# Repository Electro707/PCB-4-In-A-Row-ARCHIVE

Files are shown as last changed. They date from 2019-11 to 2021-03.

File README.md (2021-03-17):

# PCB Digital 4-In-A-Row - ARCHIVED

This a PCB is a soldering kit for a 4-In-A-Row game. This specific repo is archived. Previously I didn't use a version manager, and thus I have difference folders for different revs, while now I want to start using git as a version manager (as well as proper releases and stuff). Thus there is a new clean repo for this project, and this is here for archival purposes. 

The new repo can be found here:
[https://github.com/Electro707/PCB-4-In-A-Row](https://github.com/Electro707/PCB-4-In-A-Row)

Rev A1:
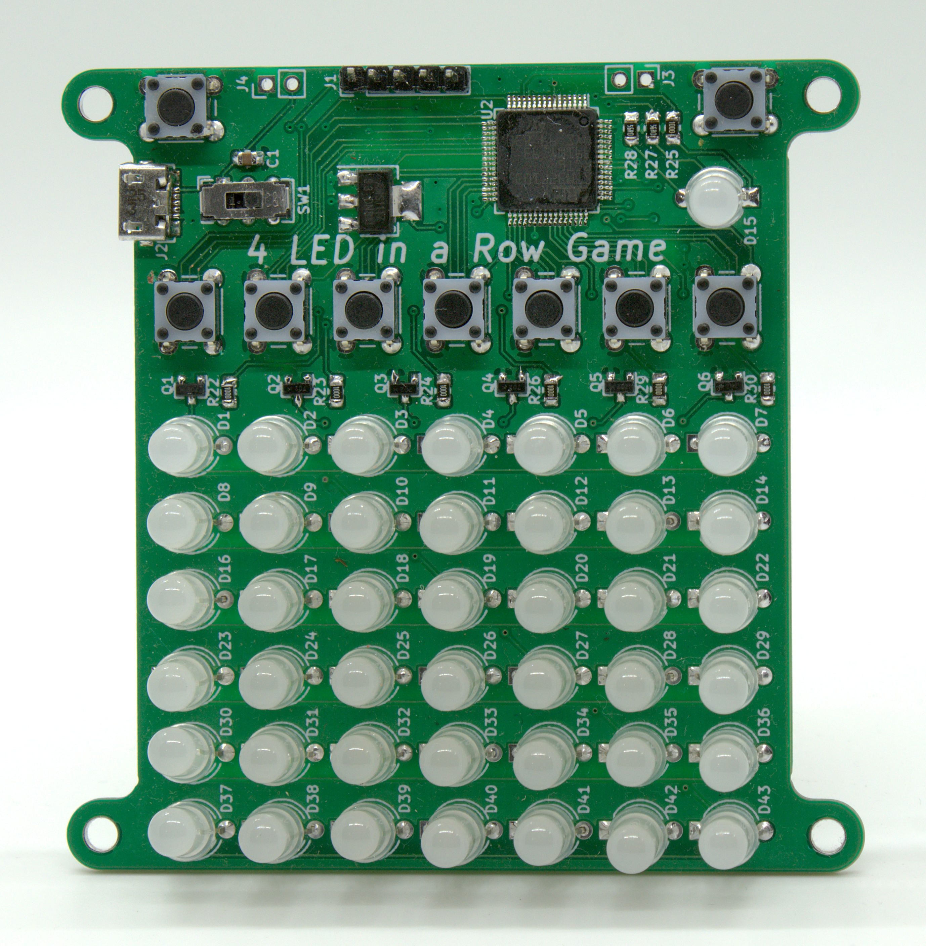
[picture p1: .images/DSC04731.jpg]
Rev A1

Rev A2:
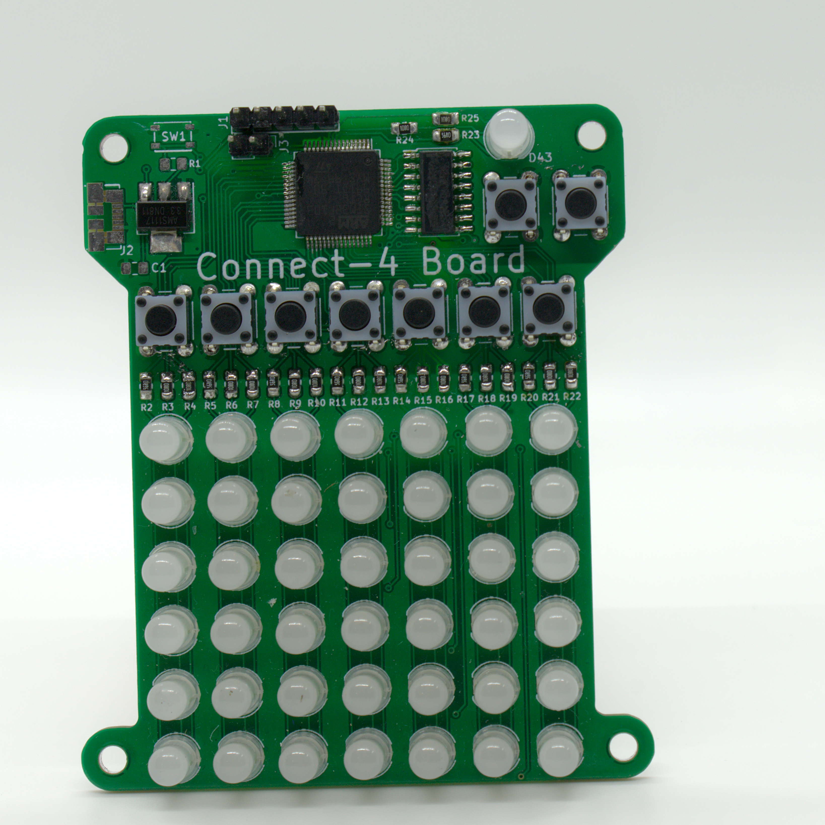
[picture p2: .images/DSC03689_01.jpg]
Rev A2

Latest Rev:
Latest Rev
## Authors

* **Jamal Bouajjaj** 

## License

See the [LICENSE.md](LICENSE.md) file for details

## Changelog 

What are those version? Well I have documented them under [CHANGELOG.md](CHANGELOG.md).

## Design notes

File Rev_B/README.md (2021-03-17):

## What is these patches??

Before I pushed the project files on GitHub, I had individual folders for each revision. So instead of having those folders uploaded, I decided to make them based on the Rev_B folder as different patches. To get the board, run the following command:

```
cd Rev_B
patch -p0 -t -R -E < ../revb*.patch
```

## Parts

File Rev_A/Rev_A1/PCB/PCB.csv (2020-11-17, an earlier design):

Source: | F:\Projects\Connect4 Board\PCB\PCB.sch
Date: | 11/10/2019 2:31:52 AM
Tool: | Eeschema (5.99.0-126-g64b5e8bee)
Component Count: | 89
Ref | Value | Footprint | Datasheet | Manufacturer | Vendor
C1 | C | Capacitor_SMD:C_0805_2012Metric_Pad1.15x1.40mm_HandSolder | ~
D1 | LED_RCGB | LED_THT:LED_D5.0mm-4_RGB | ~
D2 | LED_RCGB | LED_THT:LED_D5.0mm-4_RGB | ~
D3 | LED_RCGB | LED_THT:LED_D5.0mm-4_RGB | ~
D4 | LED_RCGB | LED_THT:LED_D5.0mm-4_RGB | ~
D5 | LED_RCGB | LED_THT:LED_D5.0mm-4_RGB | ~
D6 | LED_RCGB | LED_THT:LED_D5.0mm-4_RGB | ~
D7 | LED_RCGB | LED_THT:LED_D5.0mm-4_RGB | ~
D8 | LED_RCGB | LED_THT:LED_D5.0mm-4_RGB | ~
D9 | LED_RCGB | LED_THT:LED_D5.0mm-4_RGB | ~
D10 | LED_RCGB | LED_THT:LED_D5.0mm-4_RGB | ~
D11 | LED_RCGB | LED_THT:LED_D5.0mm-4_RGB | ~
D12 | LED_RCGB | LED_THT:LED_D5.0mm-4_RGB | ~
D13 | LED_RCGB | LED_THT:LED_D5.0mm-4_RGB | ~
D14 | LED_RCGB | LED_THT:LED_D5.0mm-4_RGB | ~
D15 | LED_RCGB | LED_THT:LED_D5.0mm-4_RGB | ~
D16 | LED_RCGB | LED_THT:LED_D5.0mm-4_RGB | ~
D17 | LED_RCGB | LED_THT:LED_D5.0mm-4_RGB | ~
D18 | LED_RCGB | LED_THT:LED_D5.0mm-4_RGB | ~
D19 | LED_RCGB | LED_THT:LED_D5.0mm-4_RGB | ~
D20 | LED_RCGB | LED_THT:LED_D5.0mm-4_RGB | ~
D21 | LED_RCGB | LED_THT:LED_D5.0mm-4_RGB | ~
D22 | LED_RCGB | LED_THT:LED_D5.0mm-4_RGB | ~
D23 | LED_RCGB | LED_THT:LED_D5.0mm-4_RGB | ~
D24 | LED_RCGB | LED_THT:LED_D5.0mm-4_RGB | ~
D25 | LED_RCGB | LED_THT:LED_D5.0mm-4_RGB | ~
D26 | LED_RCGB | LED_THT:LED_D5.0mm-4_RGB | ~
D27 | LED_RCGB | LED_THT:LED_D5.0mm-4_RGB | ~
D28 | LED_RCGB | LED_THT:LED_D5.0mm-4_RGB | ~
D29 | LED_RCGB | LED_THT:LED_D5.0mm-4_RGB | ~
D30 | LED_RCGB | LED_THT:LED_D5.0mm-4_RGB | ~
D31 | LED_RCGB | LED_THT:LED_D5.0mm-4_RGB | ~
D32 | LED_RCGB | LED_THT:LED_D5.0mm-4_RGB | ~
D33 | LED_RCGB | LED_THT:LED_D5.0mm-4_RGB | ~
D34 | LED_RCGB | LED_THT:LED_D5.0mm-4_RGB | ~
D35 | LED_RCGB | LED_THT:LED_D5.0mm-4_RGB | ~
D36 | LED_RCGB | LED_THT:LED_D5.0mm-4_RGB | ~
D37 | LED_RCGB | LED_THT:LED_D5.0mm-4_RGB | ~
D38 | LED_RCGB | LED_THT:LED_D5.0mm-4_RGB | ~
D39 | LED_RCGB | LED_THT:LED_D5.0mm-4_RGB | ~
D40 | LED_RCGB | LED_THT:LED_D5.0mm-4_RGB | ~
D41 | LED_RCGB | LED_THT:LED_D5.0mm-4_RGB | ~
D42 | LED_RCGB | LED_THT:LED_D5.0mm-4_RGB | ~
D43 | LED_RCGB | LED_THT:LED_D5.0mm-4_RGB | ~
H1 | 3.2mm Mounting Hole | MountingHole:MountingHole_3.2mm_M3 | ~
H2 | 3.2mm Mounting Hole | MountingHole:MountingHole_3.2mm_M3 | ~
H3 | 3.2mm Mounting Hole | MountingHole:MountingHole_3.2mm_M3 | ~
H4 | 3.2mm Mounting Hole | MountingHole:MountingHole_3.2mm_M3 | ~
J1 | Conn_01x05 | Connector_PinHeader_2.54mm:PinHeader_1x05_P2.54mm_Vertical | ~
J2 | USB_B_Micro | Connector_USB:USB_Micro-B_Molex_47346-0001 | ~
J3 | Power | Connector_PinHeader_2.54mm:PinHeader_1x02_P2.54mm_Vertical | ~
R1 | 1k | Resistor_SMD:R_0805_2012Metric_Pad1.15x1.40mm_HandSolder | ~
R2 | 560 | Resistor_SMD:R_0805_2012Metric_Pad1.15x1.40mm_HandSolder | ~
R3 | 560 | Resistor_SMD:R_0805_2012Metric_Pad1.15x1.40mm_HandSolder | ~
R4 | 560 | Resistor_SMD:R_0805_2012Metric_Pad1.15x1.40mm_HandSolder | ~
R5 | 560 | Resistor_SMD:R_0805_2012Metric_Pad1.15x1.40mm_HandSolder | ~
R6 | 560 | Resistor_SMD:R_0805_2012Metric_Pad1.15x1.40mm_HandSolder | ~
R7 | 560 | Resistor_SMD:R_0805_2012Metric_Pad1.15x1.40mm_HandSolder | ~
R8 | 560 | Resistor_SMD:R_0805_2012Metric_Pad1.15x1.40mm_HandSolder | ~
R9 | 560 | Resistor_SMD:R_0805_2012Metric_Pad1.15x1.40mm_HandSolder | ~
R10 | 560 | Resistor_SMD:R_0805_2012Metric_Pad1.15x1.40mm_HandSolder | ~
R11 | 560 | Resistor_SMD:R_0805_2012Metric_Pad1.15x1.40mm_HandSolder | ~
R12 | 560 | Resistor_SMD:R_0805_2012Metric_Pad1.15x1.40mm_HandSolder | ~
R13 | 560 | Resistor_SMD:R_0805_2012Metric_Pad1.15x1.40mm_HandSolder | ~
R14 | 560 | Resistor_SMD:R_0805_2012Metric_Pad1.15x1.40mm_HandSolder | ~
R15 | 560 | Resistor_SMD:R_0805_2012Metric_Pad1.15x1.40mm_HandSolder | ~
R16 | 560 | Resistor_SMD:R_0805_2012Metric_Pad1.15x1.40mm_HandSolder | ~
R17 | 560 | Resistor_SMD:R_0805_2012Metric_Pad1.15x1.40mm_HandSolder | ~
R18 | 560 | Resistor_SMD:R_0805_2012Metric_Pad1.15x1.40mm_HandSolder | ~
R19 | 560 | Resistor_SMD:R_0805_2012Metric_Pad1.15x1.40mm_HandSolder | ~
R20 | 560 | Resistor_SMD:R_0805_2012Metric_Pad1.15x1.40mm_HandSolder | ~
R21 | 560 | Resistor_SMD:R_0805_2012Metric_Pad1.15x1.40mm_HandSolder | ~
R22 | 560 | Resistor_SMD:R_0805_2012Metric_Pad1.15x1.40mm_HandSolder | ~
R23 | 560 | Resistor_SMD:R_0805_2012Metric_Pad1.15x1.40mm_HandSolder | ~
R24 | 560 | Resistor_SMD:R_0805_2012Metric_Pad1.15x1.40mm_HandSolder | ~
R25 | 560 | Resistor_SMD:R_0805_2012Metric_Pad1.15x1.40mm_HandSolder | ~
SW1 | SW_Push | Button_Switch_SMD:SW_SPST_PTS810 | ~
SW2 | SW_Push | Button_Switch_THT:SW_PUSH_6mm_H5mm
SW3 | SW_Push | Button_Switch_THT:SW_PUSH_6mm_H5mm
SW4 | SW_Push | Button_Switch_THT:SW_PUSH_6mm_H5mm
SW5 | SW_Push | Button_Switch_THT:SW_PUSH_6mm_H5mm
SW6 | SW_Push | Button_Switch_THT:SW_PUSH_6mm_H5mm
SW7 | SW_Push | Button_Switch_THT:SW_PUSH_6mm_H5mm
SW8 | SW_Push | Button_Switch_THT:SW_PUSH_6mm_H5mm
SW9 | SW_Push | Button_Switch_THT:SW_PUSH_6mm_H5mm
SW10 | SW_Push | Button_Switch_THT:SW_PUSH_6mm_H5mm
U1 | AMS1117-3.3 | Package_TO_SOT_SMD:SOT-223-3_TabPin2 | http://www.advanced-monolithic.com/pdf/ds1117.pdf
U2 | ULN2003 | Package_SO:SOP-16_4.55x10.3mm_P1.27mm | http://www.ti.com/lit/ds/symlink/uln2003a.pdf
U3 | STM32F103RCTx | Package_QFP:LQFP-64_10x10mm_P0.5mm | http://www.st.com/st-web-ui/static/active/en/resource/technical/document/datasheet/CD00191185.pdf

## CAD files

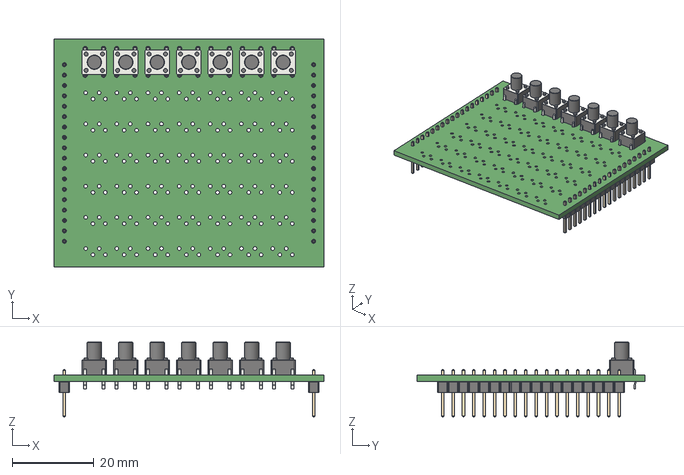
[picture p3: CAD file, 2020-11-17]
Rev_B/Rev_B/LED PCB/LED_PCB.step
66.0 x 55.9 x 18.2 mm

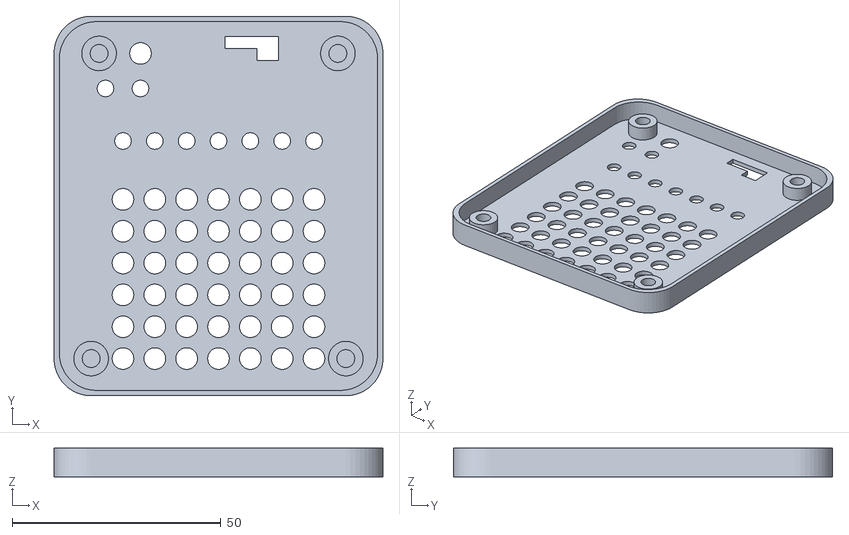
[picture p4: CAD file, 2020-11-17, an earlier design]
Rev_A/Rev_A1/CAD (Fusion360 Exports)/Case Top v24.stl
78.7 x 90.8 x 6.87

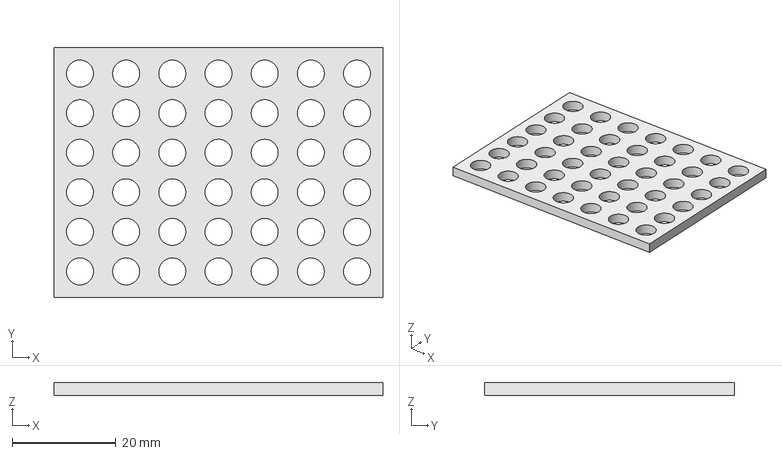
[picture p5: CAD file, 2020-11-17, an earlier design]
Rev_A/Rev_A2/LED Holder.FCStd
63.3 x 48.1 x 2.50 mm

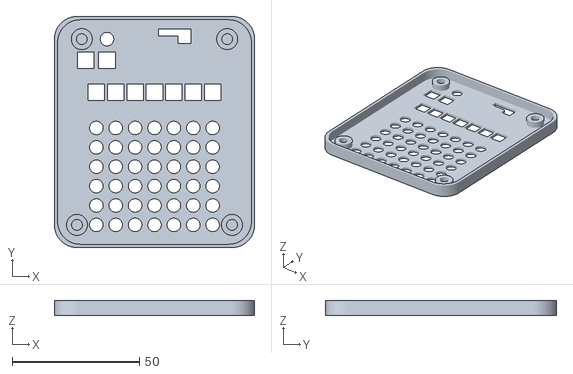
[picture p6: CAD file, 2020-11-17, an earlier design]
Rev_A/Rev_A1/CAD (Fusion360 Exports)/Case Top v29.stl
78.7 x 90.8 x 5.97

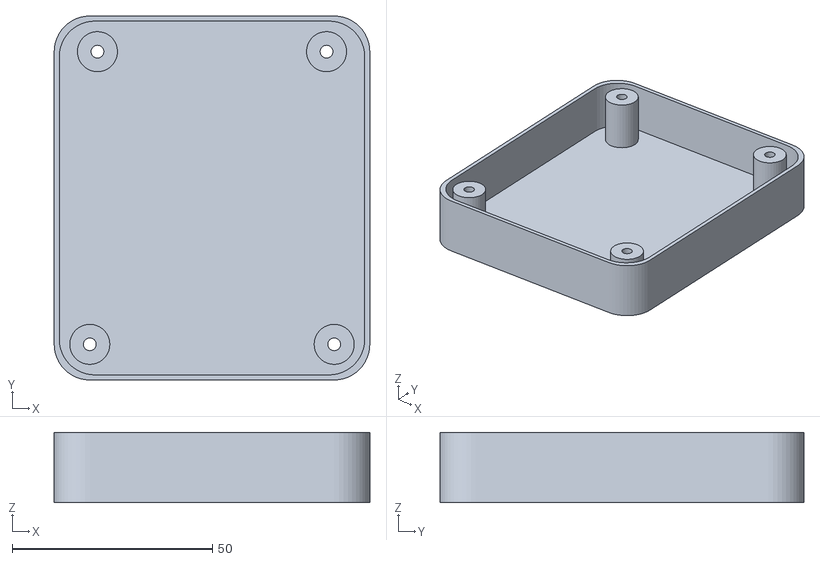
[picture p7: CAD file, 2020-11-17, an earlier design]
Rev_A/Rev_A1/CAD (Fusion360 Exports)/Buttom.stl
78.7 x 90.8 x 17.5

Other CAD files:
Rev_A/Rev_A1/CAD (Fusion360 Exports)/OldVersions/Drawing.0003.dwg
Rev_A/Rev_A1/CAD (Fusion360 Exports)/Case Top v27.stl
Rev_A/Rev_A1/CAD (Fusion360 Exports)/Drawing.dwg
Rev_A/Rev_A1/CAD (Fusion360 Exports)/Buttom Part.ipt
Rev_A/Rev_A1/CAD (Fusion360 Exports)/OldVersions/Buttom Part.0009.ipt
Rev_A/Rev_A1/CAD (Fusion360 Exports)/OldVersions/Top Part.0003.ipt
Rev_A/Rev_A1/CAD (Fusion360 Exports)/OldVersions/Whole-Assembly.0002.iam
Rev_A/Rev_A1/CAD (Fusion360 Exports)/OldVersions/Whole-Assembly.0003.iam
Rev_A/Rev_A1/CAD (Fusion360 Exports)/Top Part.ipt
Rev_A/Rev_A1/CAD (Fusion360 Exports)/Whole-Assembly.iam

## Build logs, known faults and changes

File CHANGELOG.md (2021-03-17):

This document describes the changes between the different revision:

- Rev A:
    - Rev A1:
        - Initial Release/Design
    - Rev A2: 
        - Updated to a more symetrical design. 
        - Added on-off switch
        - Replaced Darlington transistor pair IC with individual MOSFETs
- Rev B:
    - Rev B1:
        - Complete redesign to use an ATmega328P and 74HC595s instead of the STM32
        - Seperated the driver board and LED board
    - Rev B2:
        - Changed Micro-USB to USB-B
        - Added transistors to drive the rows (to allow more than 1 LED on at a time)
    - Rev B3:
        - Removed "Connect-4" trademarked silkscreen text (except I forgot to change it in the back of the PCB)
    - Rev B4:
        - Added FT230X for easy programming
        - Changed ALL "Connect-4" references to "4-In-A-Row" due to potential trademark issues
    - Rev B5 (Last one before repo archiving. Moved over to new project repo):
        - Fixed reversed USB+ and USB- data connections to the FT230X
        - Changed some silkscreen text

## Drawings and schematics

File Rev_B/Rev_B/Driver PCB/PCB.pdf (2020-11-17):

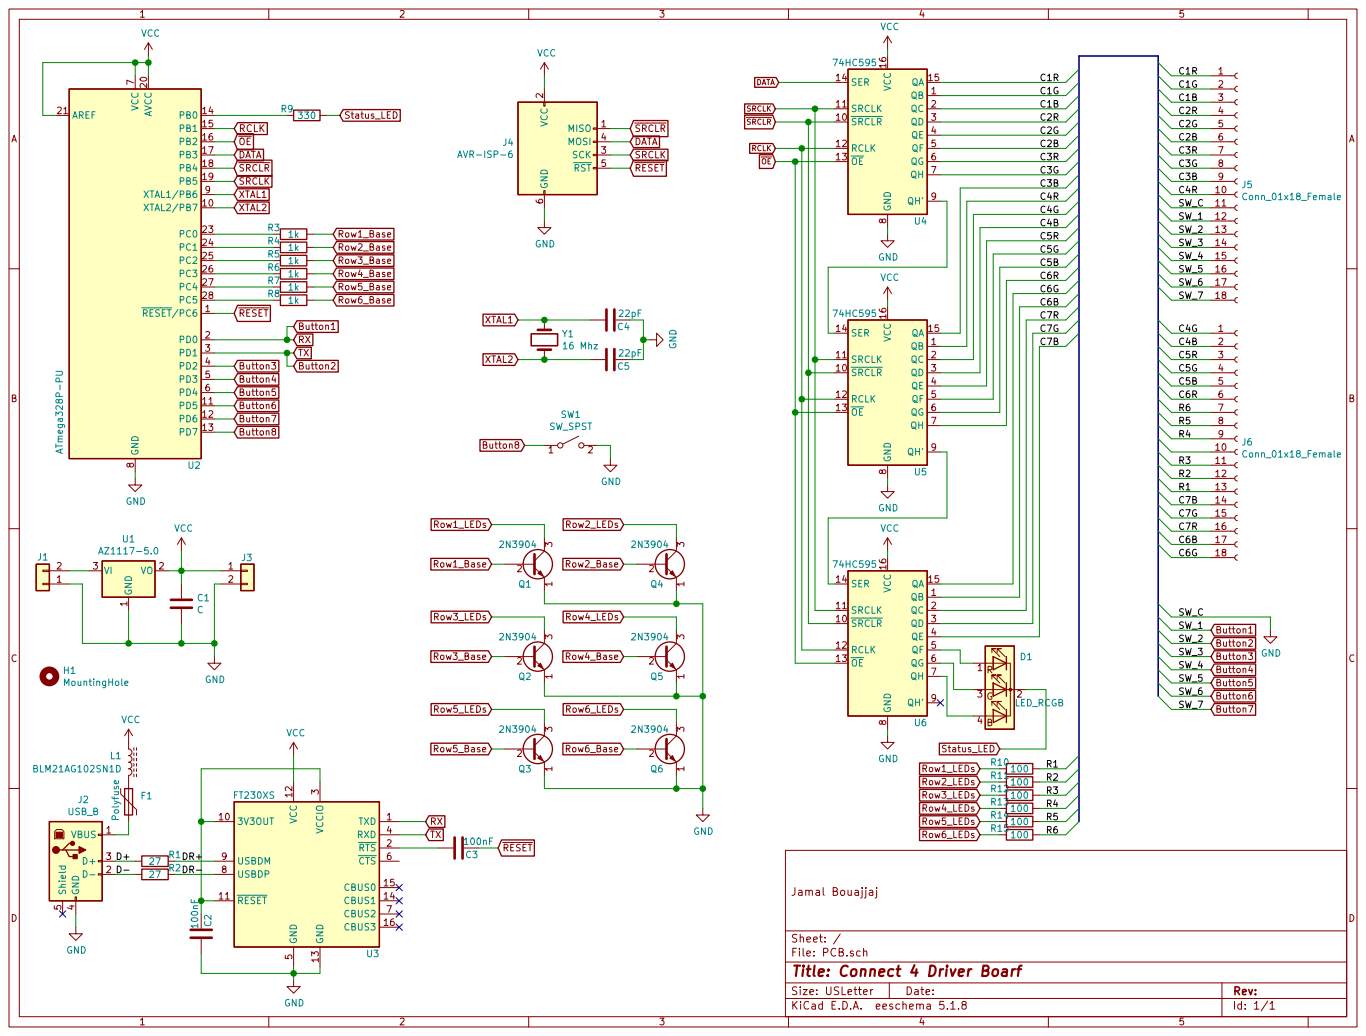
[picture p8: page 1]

Id: 1/1 Title: Connect 4 Driver Boarf File: PCB.sch Sheet: / Jamal Bouajjaj

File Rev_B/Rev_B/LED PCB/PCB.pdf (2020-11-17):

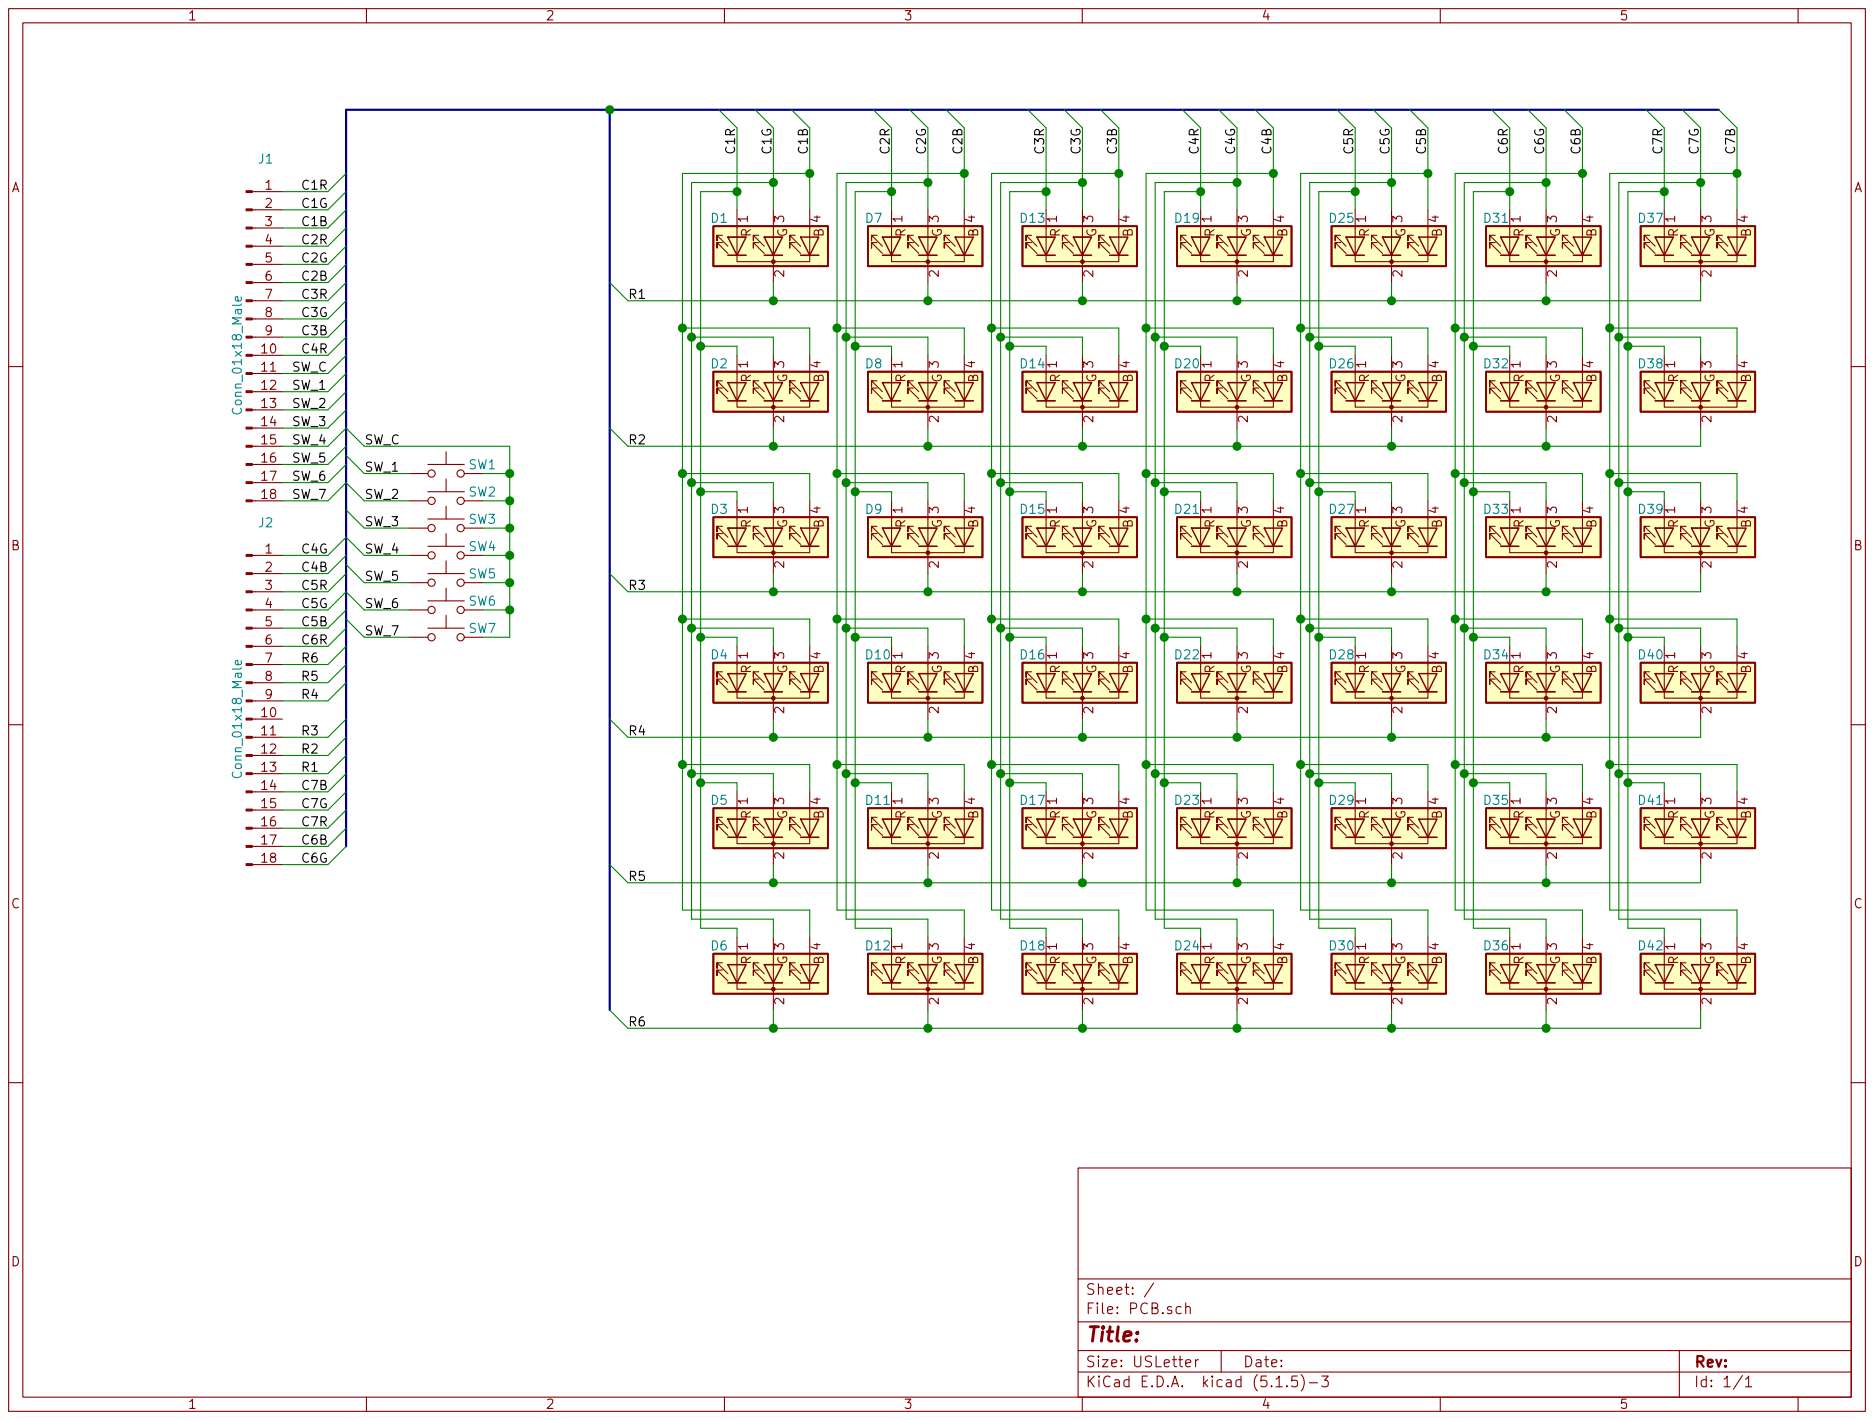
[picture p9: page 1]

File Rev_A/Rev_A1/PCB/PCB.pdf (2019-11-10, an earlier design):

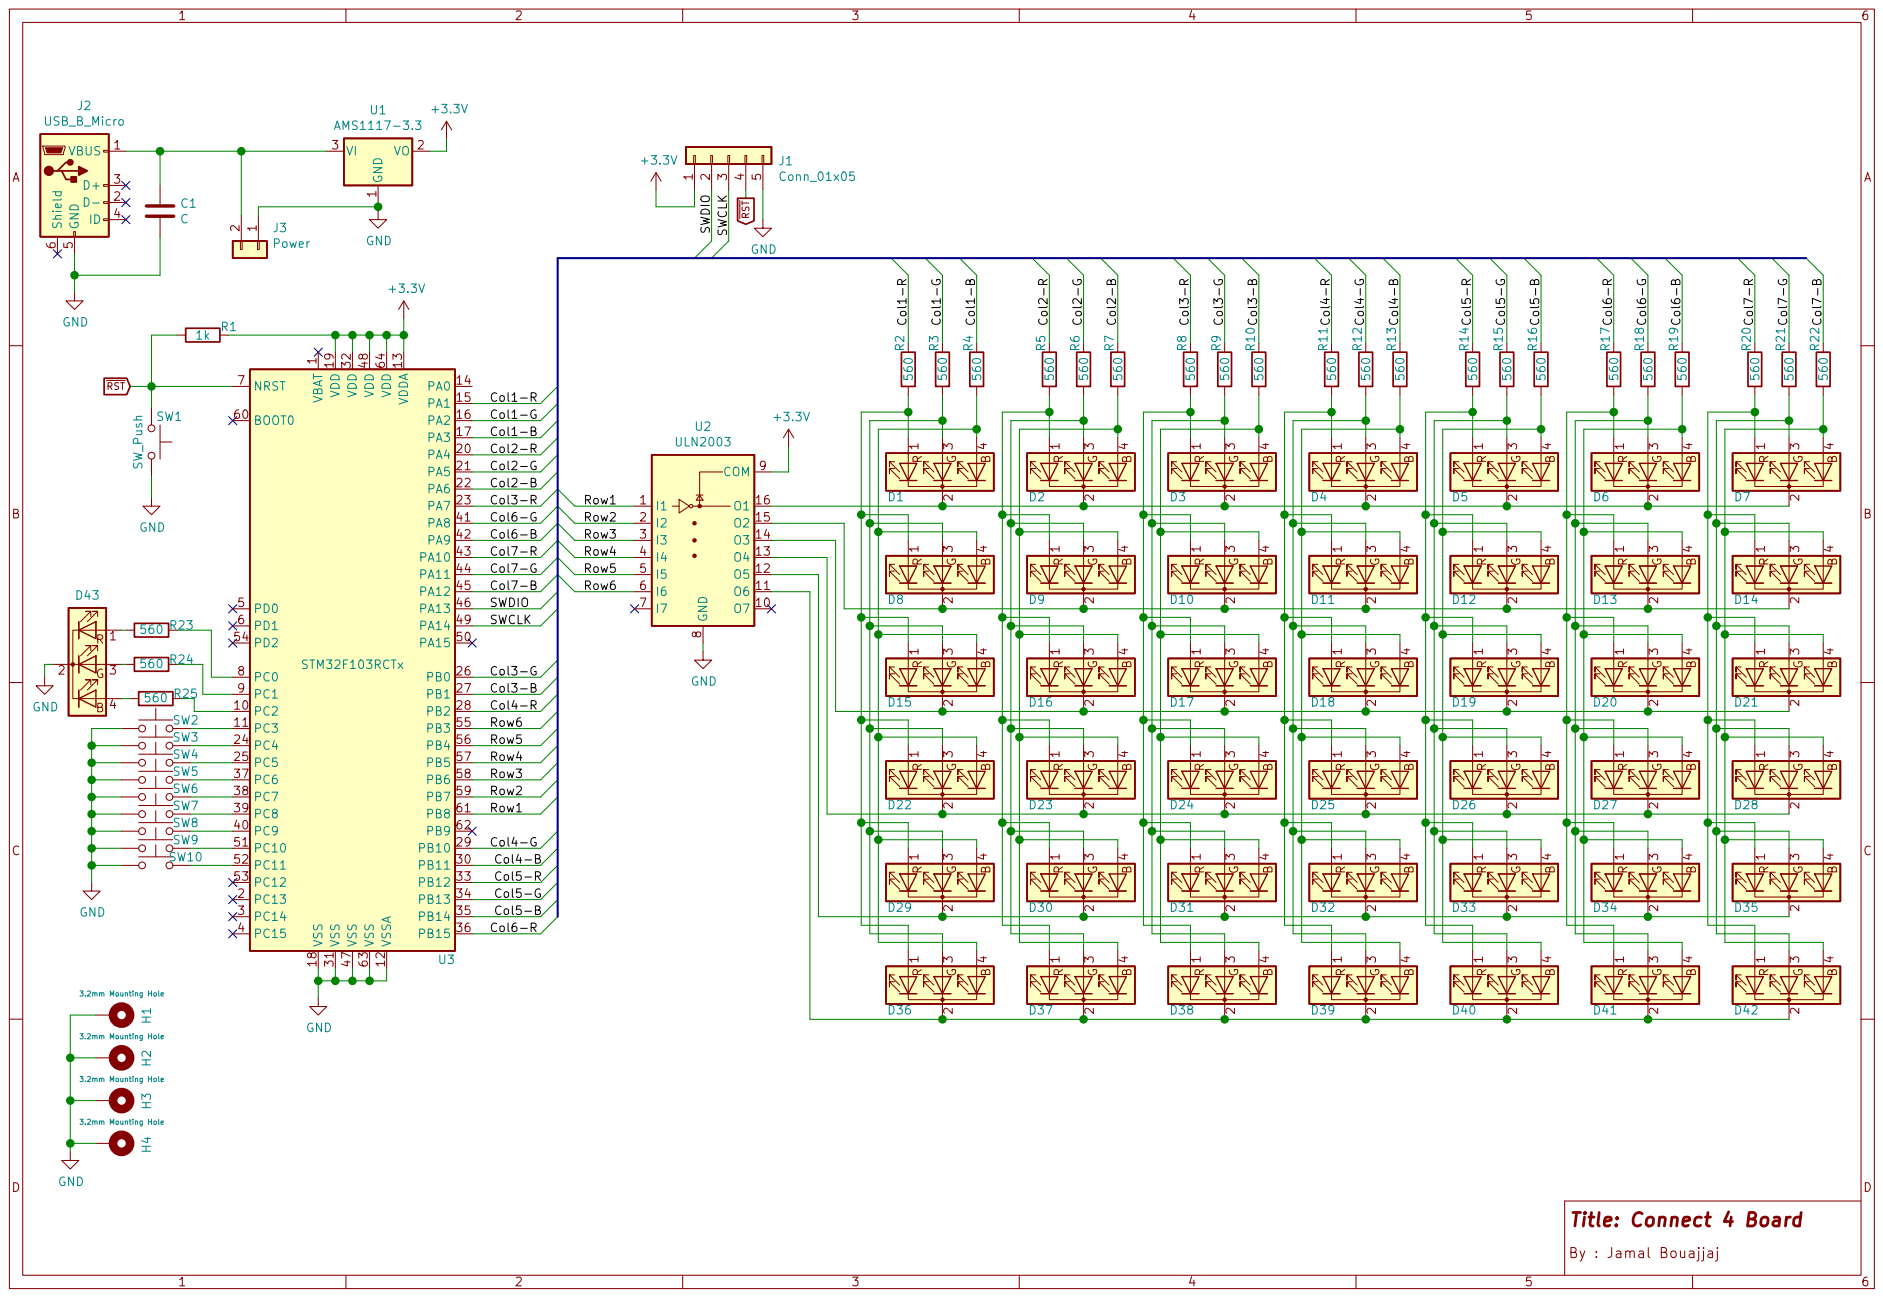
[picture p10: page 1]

1 VDD 19 VDD 32 VDD 48 VDD 64 VDDA 13 VSS 18 VSS 31 VSS 47 VSS 63 VSSA 12U3 STM32F103RCTx 2

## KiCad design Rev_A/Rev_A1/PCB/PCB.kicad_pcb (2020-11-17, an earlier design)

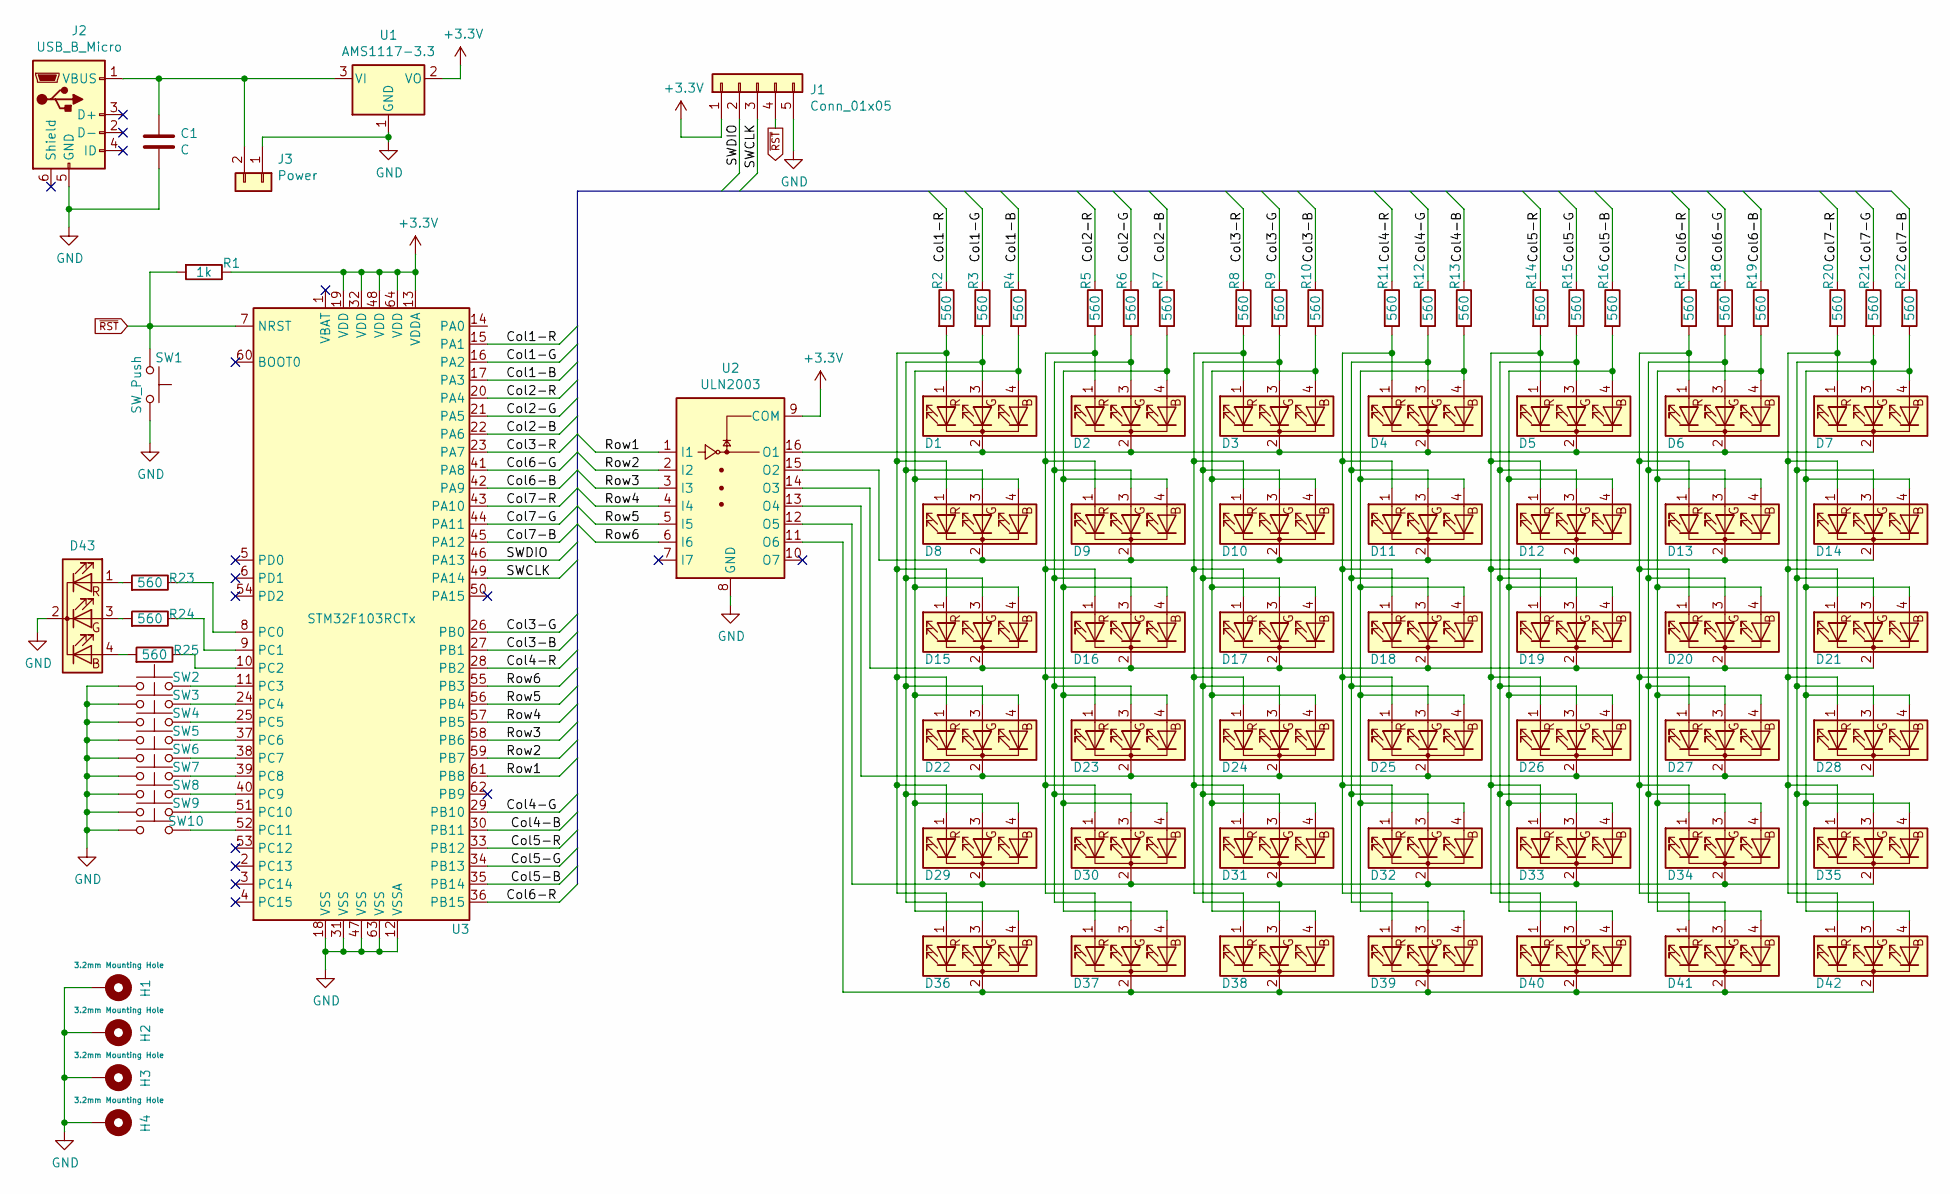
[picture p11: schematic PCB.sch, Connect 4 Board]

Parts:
C1: C; C_0805_2012Metric_Pad1.15x1.40mm_HandSolder
D1, D2, D3, D4, D5, D6, D7, D8, D9, D10, D11, D12, D13, D14, D15, D16, D17, D18, D19, D20, D21, D22, D23, D24, D25, D26, D27, D28, D29, D30, D31, D32, D33, D34, D35, D36, D37, D38, D39, D40, D41, D42, D43: LED_RCGB; LED_D5.0mm-4_RGB
H1, H2, H3, H4: 3.2mm Mounting Hole; MountingHole_3.2mm_M3
J1: Conn_01x05; PinHeader_1x05_P2.54mm_Vertical
J2: USB_B_Micro; USB_Micro-B_Molex_47346-0001
J3: Power; PinHeader_1x02_P2.54mm_Vertical
R1: 1k; R_0805_2012Metric_Pad1.15x1.40mm_HandSolder
R2, R3, R4, R5, R6, R7, R8, R9, R10, R11, R12, R13, R14, R15, R16, R17, R18, R19, R20, R21, R22, R23, R24, R25: 560; R_0805_2012Metric_Pad1.15x1.40mm_HandSolder
SW1: SW_Push; SW_SPST_PTS810
SW2, SW3, SW4, SW5, SW6, SW7, SW8, SW9, SW10: SW_Push; SW_PUSH_6mm_H5mm
U1: AMS1117-3.3; SOT-223-3_TabPin2
U2: ULN2003; SOP-16_4.55x10.3mm_P1.27mm
U3: STM32F103RCTx; LQFP-64_10x10mm_P0.5mm

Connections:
+3V3: J1.1, R1.1, U1.2 (VO), U2.9 (COM), U3.13 (VDDA), U3.19 (VDD), U3.32 (VDD), U3.48 (VDD), U3.64 (VDD)
/Col1-B: R4.1, U3.17 (PA3)
/Col1-G: R3.1, U3.16 (PA2)
/Col1-R: R2.1, U3.15 (PA1)
/Col2-B: R7.1, U3.22 (PA6)
/Col2-G: R6.1, U3.21 (PA5)
/Col2-R: R5.1, U3.20 (PA4)
/Col3-B: R10.1, U3.27 (PB1)
/Col3-G: R9.1, U3.26 (PB0)
/Col3-R: R8.1, U3.23 (PA7)
/Col4-B: R13.1, U3.30 (PB11)
/Col4-G: R12.1, U3.29 (PB10)
/Col4-R: R11.1, U3.28 (PB2)
/Col5-B: R16.1, U3.35 (PB14)
/Col5-G: R15.1, U3.34 (PB13)
/Col5-R: R14.1, U3.33 (PB12)
/Col6-B: R19.1, U3.42 (PA9)
/Col6-G: R18.1, U3.41 (PA8)
/Col6-R: R17.1, U3.36 (PB15)
/Col7-B: R22.1, U3.45 (PA12)
/Col7-G: R21.1, U3.44 (PA11)
/Col7-R: R20.1, U3.43 (PA10)
/Row1: U2.1 (I1), U3.61 (PB8)
/Row2: U2.2 (I2), U3.59 (PB7)
/Row3: U2.3 (I3), U3.58 (PB6)
/Row4: U2.4 (I4), U3.57 (PB5)
/Row5: U2.5 (I5), U3.56 (PB4)
/Row6: U2.6 (I6), U3.55 (PB3)
/SWCLK: J1.3, U3.49 (PA14)
/SWDIO: J1.2, U3.46 (PA13)
GND: C1.2, D43.2 (K), H1.1, H2.1, H3.1, H4.1, J1.5, J2.5 (GND), J3.1, SW1.2, SW2.1, SW3.1, SW4.1, SW5.1, SW6.1, SW7.1, SW8.1, SW9.1, SW10.1, U1.1 (GND), U2.8 (GND), U3.12 (VSSA), U3.18 (VSS), U3.31 (VSS), U3.47 (VSS), U3.63 (VSS)
unnamed: C1.1, J2.1 (VBUS), J3.2, U1.3 (VI)
unnamed: D1.1 (RA), D8.1 (RA), D15.1 (RA), D22.1 (RA), D29.1 (RA), D36.1 (RA), R2.2
unnamed: D1.2 (K), D2.2 (K), D3.2 (K), D4.2 (K), D5.2 (K), D6.2 (K), D7.2 (K), U2.16 (O1)
unnamed: D1.3 (GA), D8.3 (GA), D15.3 (GA), D22.3 (GA), D29.3 (GA), D36.3 (GA), R3.2
unnamed: D1.4 (BA), D8.4 (BA), D15.4 (BA), D22.4 (BA), D29.4 (BA), D36.4 (BA), R4.2
unnamed: D3.1 (RA), D10.1 (RA), D17.1 (RA), D24.1 (RA), D31.1 (RA), D38.1 (RA), R8.2
unnamed: D8.2 (K), D9.2 (K), D10.2 (K), D11.2 (K), D12.2 (K), D13.2 (K), D14.2 (K), U2.15 (O2)
unnamed: D3.3 (GA), D10.3 (GA), D17.3 (GA), D24.3 (GA), D31.3 (GA), D38.3 (GA), R9.2
unnamed: D3.4 (BA), D10.4 (BA), D17.4 (BA), D24.4 (BA), D31.4 (BA), D38.4 (BA), R10.2
unnamed: D4.1 (RA), D11.1 (RA), D18.1 (RA), D25.1 (RA), D32.1 (RA), D39.1 (RA), R11.2
unnamed: D4.3 (GA), D11.3 (GA), D18.3 (GA), D25.3 (GA), D32.3 (GA), D39.3 (GA), R12.2
unnamed: D4.4 (BA), D11.4 (BA), D18.4 (BA), D25.4 (BA), D32.4 (BA), D39.4 (BA), R13.2
unnamed: D5.1 (RA), D12.1 (RA), D19.1 (RA), D26.1 (RA), D33.1 (RA), D40.1 (RA), R14.2
unnamed: D5.3 (GA), D12.3 (GA), D19.3 (GA), D26.3 (GA), D33.3 (GA), D40.3 (GA), R15.2
unnamed: D5.4 (BA), D12.4 (BA), D19.4 (BA), D26.4 (BA), D33.4 (BA), D40.4 (BA), R16.2
unnamed: D6.1 (RA), D13.1 (RA), D20.1 (RA), D27.1 (RA), D34.1 (RA), D41.1 (RA), R17.2
unnamed: D6.3 (GA), D13.3 (GA), D20.3 (GA), D27.3 (GA), D34.3 (GA), D41.3 (GA), R18.2
unnamed: D6.4 (BA), D13.4 (BA), D20.4 (BA), D27.4 (BA), D34.4 (BA), D41.4 (BA), R19.2
unnamed: D7.1 (RA), D14.1 (RA), D21.1 (RA), D28.1 (RA), D35.1 (RA), D42.1 (RA), R20.2
unnamed: D7.3 (GA), D14.3 (GA), D21.3 (GA), D28.3 (GA), D35.3 (GA), D42.3 (GA), R21.2
unnamed: D7.4 (BA), D14.4 (BA), D21.4 (BA), D28.4 (BA), D35.4 (BA), D42.4 (BA), R22.2
unnamed: D15.2 (K), D16.2 (K), D17.2 (K), D18.2 (K), D19.2 (K), D20.2 (K), D21.2 (K), U2.14 (O3)
unnamed: D2.1 (RA), D9.1 (RA), D16.1 (RA), D23.1 (RA), D30.1 (RA), D37.1 (RA), R5.2
unnamed: D2.3 (GA), D9.3 (GA), D16.3 (GA), D23.3 (GA), D30.3 (GA), D37.3 (GA), R6.2
unnamed: D2.4 (BA), D9.4 (BA), D16.4 (BA), D23.4 (BA), D30.4 (BA), D37.4 (BA), R7.2
unnamed: D22.2 (K), D23.2 (K), D24.2 (K), D25.2 (K), D26.2 (K), D27.2 (K), D28.2 (K), U2.13 (O4)
unnamed: D29.2 (K), D30.2 (K), D31.2 (K), D32.2 (K), D33.2 (K), D34.2 (K), D35.2 (K), U2.12 (O5)
unnamed: D36.2 (K), D37.2 (K), D38.2 (K), D39.2 (K), D40.2 (K), D41.2 (K), D42.2 (K), U2.11 (O6)
unnamed: D43.1 (RA), R23.2
unnamed: D43.3 (GA), R24.2
unnamed: D43.4 (BA), R25.2
unnamed: R23.1, U3.8 (PC0)
unnamed: R24.1, U3.9 (PC1)
unnamed: R25.1, U3.10 (PC2)
unnamed: SW2.2, U3.11 (PC3)
unnamed: SW3.2, U3.24 (PC4)
unnamed: SW4.2, U3.25 (PC5)
unnamed: SW5.2, U3.37 (PC6)
unnamed: SW6.2, U3.38 (PC7)
unnamed: SW7.2, U3.39 (PC8)
unnamed: SW8.2, U3.40 (PC9)
unnamed: SW9.2, U3.51 (PC10)
unnamed: SW10.2, U3.52 (PC11)
~RST: J1.4, R1.2, SW1.1, U3.7 (NRST)

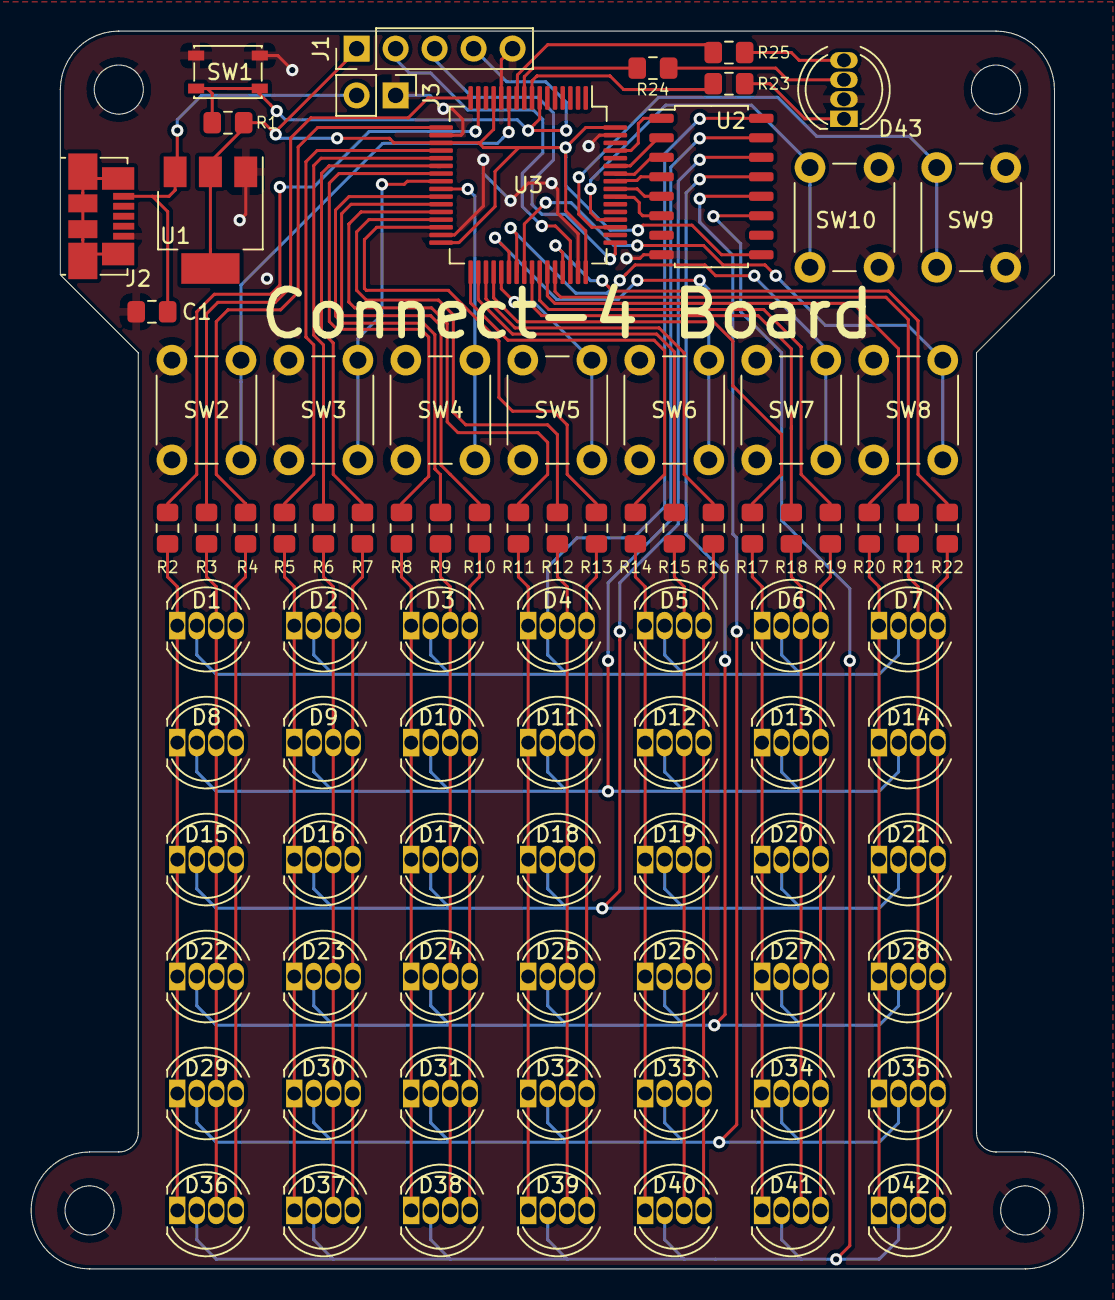
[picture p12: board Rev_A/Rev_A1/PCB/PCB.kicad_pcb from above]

Board: 2 copper layers, 68.6 x 80.6 mm, 89 parts (0 on the bottom side), 75 nets.

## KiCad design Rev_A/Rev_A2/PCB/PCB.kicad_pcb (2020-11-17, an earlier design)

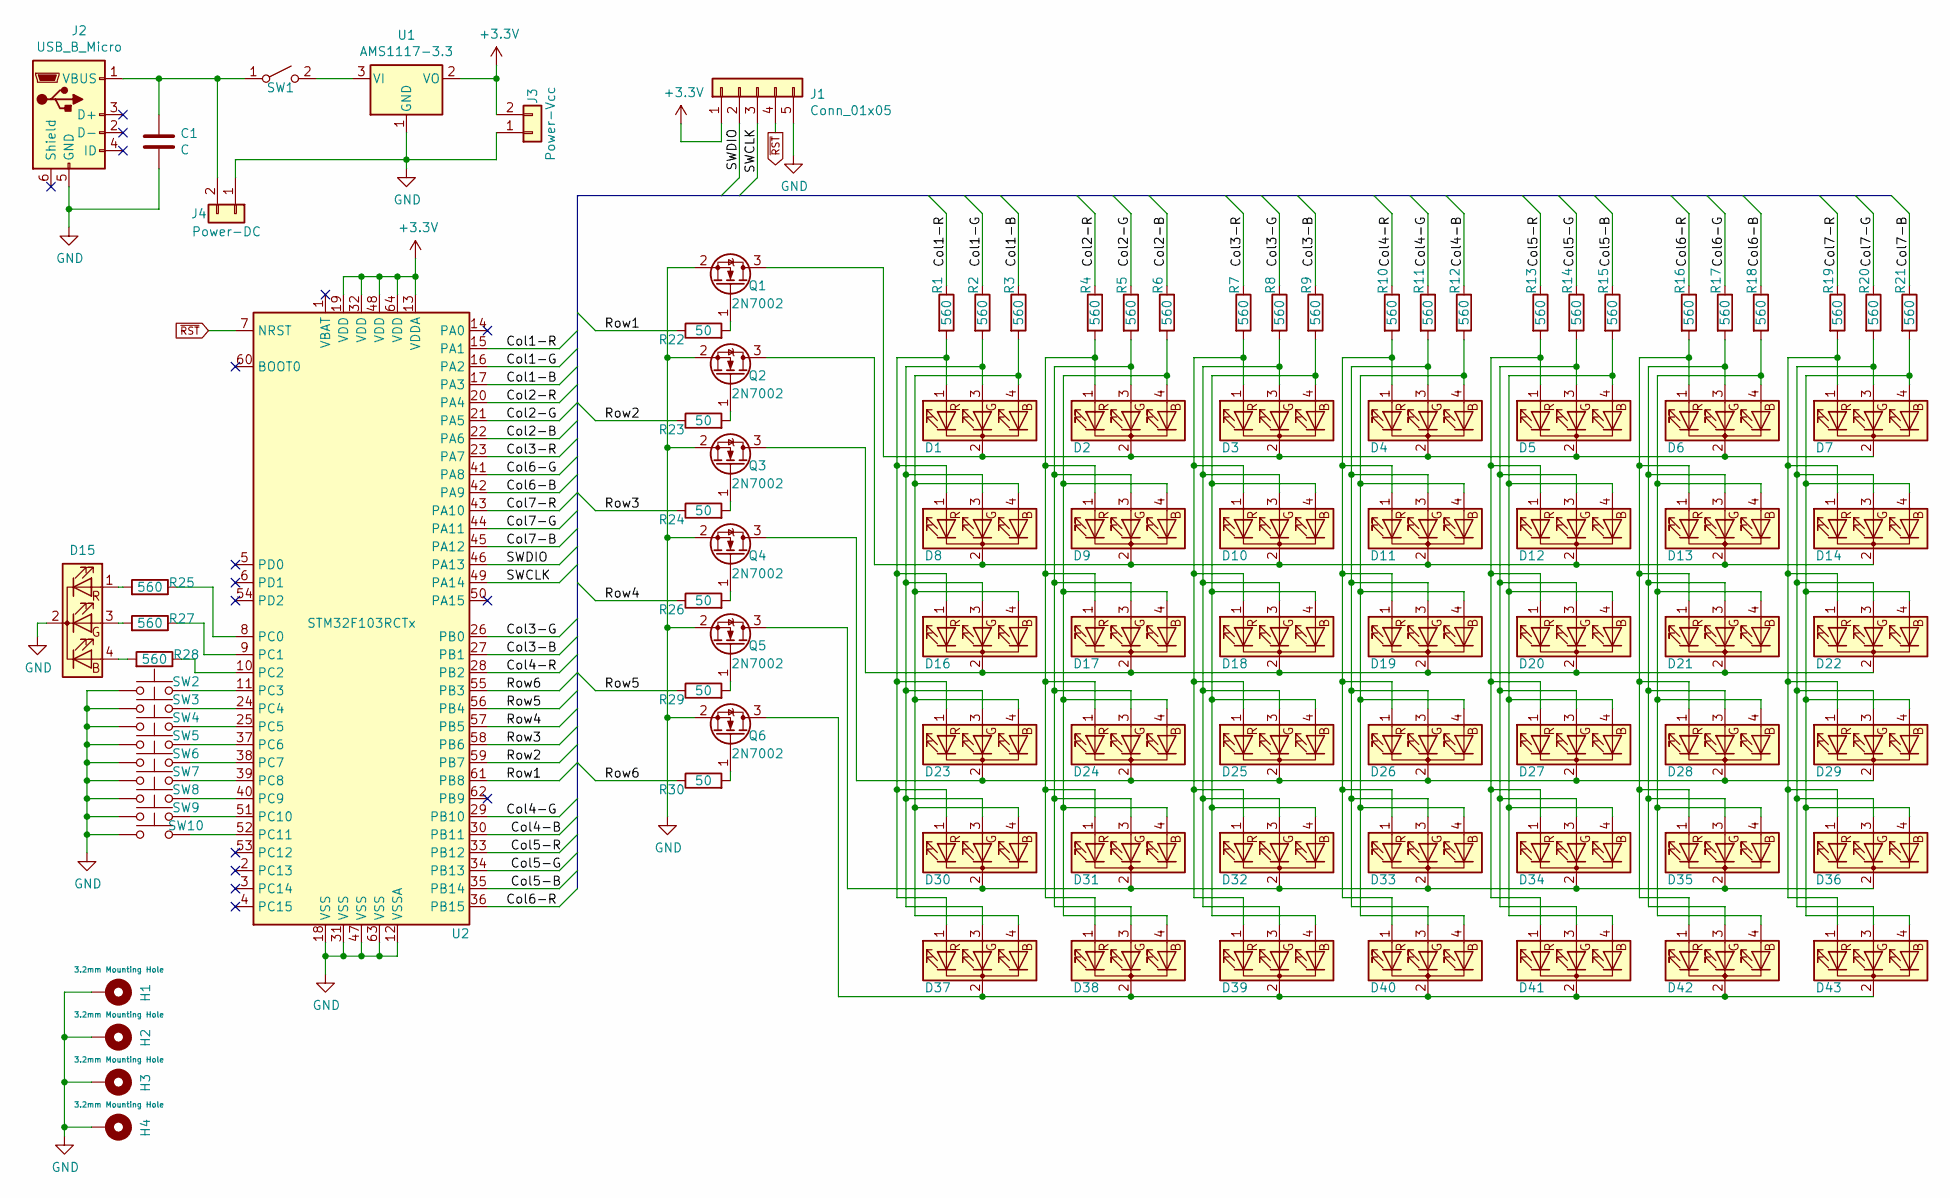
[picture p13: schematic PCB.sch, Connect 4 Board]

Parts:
C1: C; C_0805_2012Metric_Pad1.15x1.40mm_HandSolder
D1, D2, D3, D4, D5, D6, D7, D8, D9, D10, D11, D12, D13, D14, D15, D16, D17, D18, D19, D20, D21, D22, D23, D24, D25, D26, D27, D28, D29, D30, D31, D32, D33, D34, D35, D36, D37, D38, D39, D40, D41, D42, D43: LED_RCGB; LED_D5.0mm-4_RGB_Wide_Pins
H1, H2, H3, H4: 3.2mm Mounting Hole; MountingHole_3.2mm_M3
J1: Conn_01x05; PinHeader_1x05_P2.54mm_Vertical
J2: USB_B_Micro; USB_Micro-B_Molex_47346-0001
J3: Power-Vcc; PinHeader_1x02_P2.54mm_Vertical
J4: Power-DC; PinHeader_1x02_P2.54mm_Vertical
Q1, Q2, Q3, Q4, Q5, Q6: 2N7002; SOT-23
R1, R2, R3, R4, R5, R6, R7, R8, R9, R10, R11, R12, R13, R14, R15, R16, R17, R18, R19, R20, R21, R25, R27, R28: 560; R_0805_2012Metric_Pad1.15x1.40mm_HandSolder
R22, R23, R24, R26, R29, R30: 50; R_0805_2012Metric_Pad1.15x1.40mm_HandSolder
SW1: SW_SPST; SW_CuK_JS202011CQN_DPDT_Straight
SW2, SW3, SW4, SW5, SW6, SW7, SW8, SW9, SW10: SW_Push; SW_PUSH_6mm_H5mm
U1: AMS1117-3.3; SOT-223-3_TabPin2
U2: STM32F103RCTx; LQFP-64_10x10mm_P0.5mm

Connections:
+3V3: J1.1, J3.2, U1.2 (VO), U2.13 (VDDA), U2.19 (VDD), U2.32 (VDD), U2.48 (VDD), U2.64 (VDD)
/Col1-B: R3.1, U2.17 (PA3)
/Col1-G: R2.1, U2.16 (PA2)
/Col1-R: R1.1, U2.15 (PA1)
/Col2-B: R6.1, U2.22 (PA6)
/Col2-G: R5.1, U2.21 (PA5)
/Col2-R: R4.1, U2.20 (PA4)
/Col3-B: R9.1, U2.27 (PB1)
/Col3-G: R8.1, U2.26 (PB0)
/Col3-R: R7.1, U2.23 (PA7)
/Col4-B: R12.1, U2.30 (PB11)
/Col4-G: R11.1, U2.29 (PB10)
/Col4-R: R10.1, U2.28 (PB2)
/Col5-B: R15.1, U2.35 (PB14)
/Col5-G: R14.1, U2.34 (PB13)
/Col5-R: R13.1, U2.33 (PB12)
/Col6-B: R18.1, U2.42 (PA9)
/Col6-G: R17.1, U2.41 (PA8)
/Col6-R: R16.1, U2.36 (PB15)
/Col7-B: R21.1, U2.45 (PA12)
/Col7-G: R20.1, U2.44 (PA11)
/Col7-R: R19.1, U2.43 (PA10)
/Row1: R22.1, U2.61 (PB8)
/Row2: R23.1, U2.59 (PB7)
/Row3: R24.1, U2.58 (PB6)
/Row4: R26.1, U2.57 (PB5)
/Row5: R29.1, U2.56 (PB4)
/Row6: R30.1, U2.55 (PB3)
/SWCLK: J1.3, U2.49 (PA14)
/SWDIO: J1.2, U2.46 (PA13)
GND: C1.2, D15.2 (K), H1.1, H2.1, H3.1, H4.1, J1.5, J2.5 (GND), J3.1, J4.1, Q1.2 (S), Q2.2 (S), Q3.2 (S), Q4.2 (S), Q5.2 (S), Q6.2 (S), SW2.1, SW3.1, SW4.1, SW5.1, SW6.1, SW7.1, SW8.1, SW9.1, SW10.1, U1.1 (GND), U2.12 (VSSA), U2.18 (VSS), U2.31 (VSS), U2.47 (VSS), U2.63 (VSS)
unnamed: C1.1, J2.1 (VBUS), J4.2, SW1.1 (A)
unnamed: D1.1 (RA), D8.1 (RA), D16.1 (RA), D23.1 (RA), D30.1 (RA), D37.1 (RA), R1.2
unnamed: D1.2 (K), D2.2 (K), D3.2 (K), D4.2 (K), D5.2 (K), D6.2 (K), D7.2 (K), Q1.3 (D)
unnamed: D1.3 (GA), D8.3 (GA), D16.3 (GA), D23.3 (GA), D30.3 (GA), D37.3 (GA), R2.2
unnamed: D1.4 (BA), D8.4 (BA), D16.4 (BA), D23.4 (BA), D30.4 (BA), D37.4 (BA), R3.2
unnamed: D3.1 (RA), D10.1 (RA), D18.1 (RA), D25.1 (RA), D32.1 (RA), D39.1 (RA), R7.2
unnamed: D8.2 (K), D9.2 (K), D10.2 (K), D11.2 (K), D12.2 (K), D13.2 (K), D14.2 (K), Q2.3 (D)
unnamed: D3.3 (GA), D10.3 (GA), D18.3 (GA), D25.3 (GA), D32.3 (GA), D39.3 (GA), R8.2
unnamed: D3.4 (BA), D10.4 (BA), D18.4 (BA), D25.4 (BA), D32.4 (BA), D39.4 (BA), R9.2
unnamed: D4.1 (RA), D11.1 (RA), D19.1 (RA), D26.1 (RA), D33.1 (RA), D40.1 (RA), R10.2
unnamed: D4.3 (GA), D11.3 (GA), D19.3 (GA), D26.3 (GA), D33.3 (GA), D40.3 (GA), R11.2
unnamed: D4.4 (BA), D11.4 (BA), D19.4 (BA), D26.4 (BA), D33.4 (BA), D40.4 (BA), R12.2
unnamed: D5.1 (RA), D12.1 (RA), D20.1 (RA), D27.1 (RA), D34.1 (RA), D41.1 (RA), R13.2
unnamed: D5.3 (GA), D12.3 (GA), D20.3 (GA), D27.3 (GA), D34.3 (GA), D41.3 (GA), R14.2
unnamed: D5.4 (BA), D12.4 (BA), D20.4 (BA), D27.4 (BA), D34.4 (BA), D41.4 (BA), R15.2
unnamed: D6.1 (RA), D13.1 (RA), D21.1 (RA), D28.1 (RA), D35.1 (RA), D42.1 (RA), R16.2
unnamed: D6.3 (GA), D13.3 (GA), D21.3 (GA), D28.3 (GA), D35.3 (GA), D42.3 (GA), R17.2
unnamed: D6.4 (BA), D13.4 (BA), D21.4 (BA), D28.4 (BA), D35.4 (BA), D42.4 (BA), R18.2
unnamed: D7.1 (RA), D14.1 (RA), D22.1 (RA), D29.1 (RA), D36.1 (RA), D43.1 (RA), R19.2
unnamed: D7.3 (GA), D14.3 (GA), D22.3 (GA), D29.3 (GA), D36.3 (GA), D43.3 (GA), R20.2
unnamed: D7.4 (BA), D14.4 (BA), D22.4 (BA), D29.4 (BA), D36.4 (BA), D43.4 (BA), R21.2
unnamed: D15.1 (RA), R25.2
unnamed: D15.3 (GA), R27.2
unnamed: D15.4 (BA), R28.2
unnamed: D16.2 (K), D17.2 (K), D18.2 (K), D19.2 (K), D20.2 (K), D21.2 (K), D22.2 (K), Q3.3 (D)
unnamed: D2.1 (RA), D9.1 (RA), D17.1 (RA), D24.1 (RA), D31.1 (RA), D38.1 (RA), R4.2
unnamed: D2.3 (GA), D9.3 (GA), D17.3 (GA), D24.3 (GA), D31.3 (GA), D38.3 (GA), R5.2
unnamed: D2.4 (BA), D9.4 (BA), D17.4 (BA), D24.4 (BA), D31.4 (BA), D38.4 (BA), R6.2
unnamed: D23.2 (K), D24.2 (K), D25.2 (K), D26.2 (K), D27.2 (K), D28.2 (K), D29.2 (K), Q4.3 (D)
unnamed: D30.2 (K), D31.2 (K), D32.2 (K), D33.2 (K), D34.2 (K), D35.2 (K), D36.2 (K), Q5.3 (D)
unnamed: D37.2 (K), D38.2 (K), D39.2 (K), D40.2 (K), D41.2 (K), D42.2 (K), D43.2 (K), Q6.3 (D)
unnamed: Q1.1 (G), R22.2
unnamed: Q2.1 (G), R23.2
unnamed: Q3.1 (G), R24.2
unnamed: Q4.1 (G), R26.2
unnamed: Q5.1 (G), R29.2
unnamed: Q6.1 (G), R30.2
unnamed: R25.1, U2.8 (PC0)
unnamed: R27.1, U2.9 (PC1)
unnamed: R28.1, U2.10 (PC2)
unnamed: SW1.2 (B), U1.3 (VI)
unnamed: SW2.2, U2.11 (PC3)
unnamed: SW3.2, U2.24 (PC4)
unnamed: SW4.2, U2.25 (PC5)
unnamed: SW5.2, U2.37 (PC6)
unnamed: SW6.2, U2.38 (PC7)
unnamed: SW7.2, U2.39 (PC8)
unnamed: SW8.2, U2.40 (PC9)
unnamed: SW9.2, U2.51 (PC10)
unnamed: SW10.2, U2.52 (PC11)
~RST: J1.4, U2.7 (NRST)

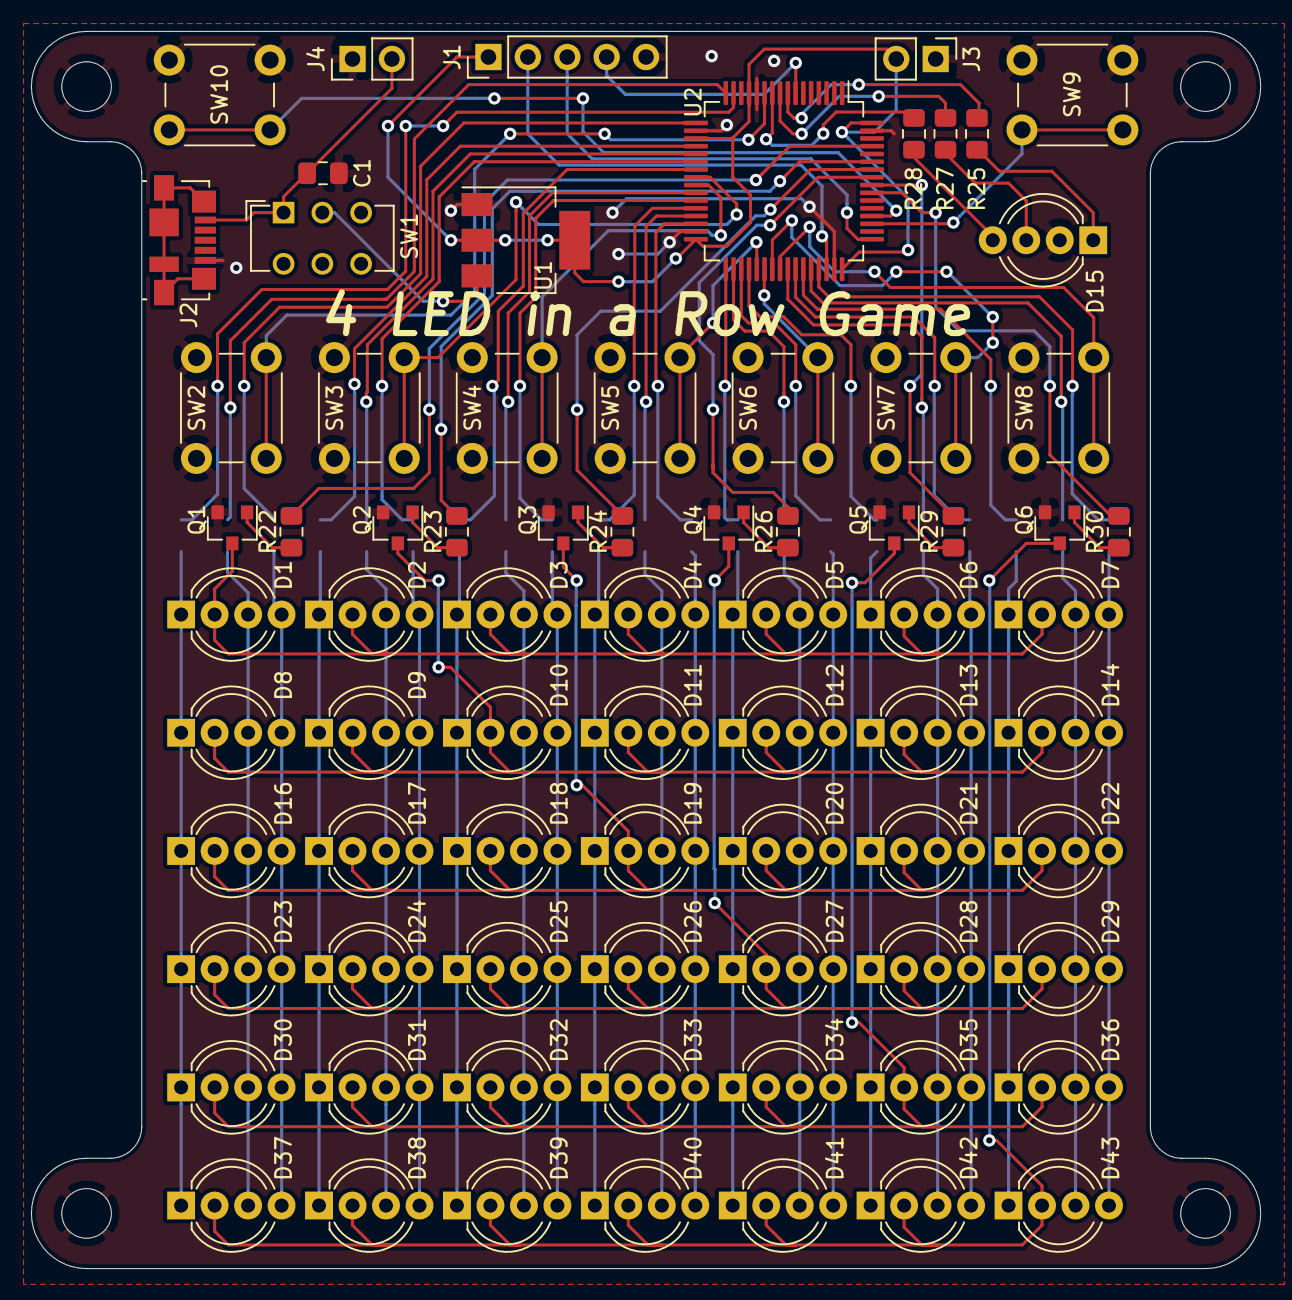
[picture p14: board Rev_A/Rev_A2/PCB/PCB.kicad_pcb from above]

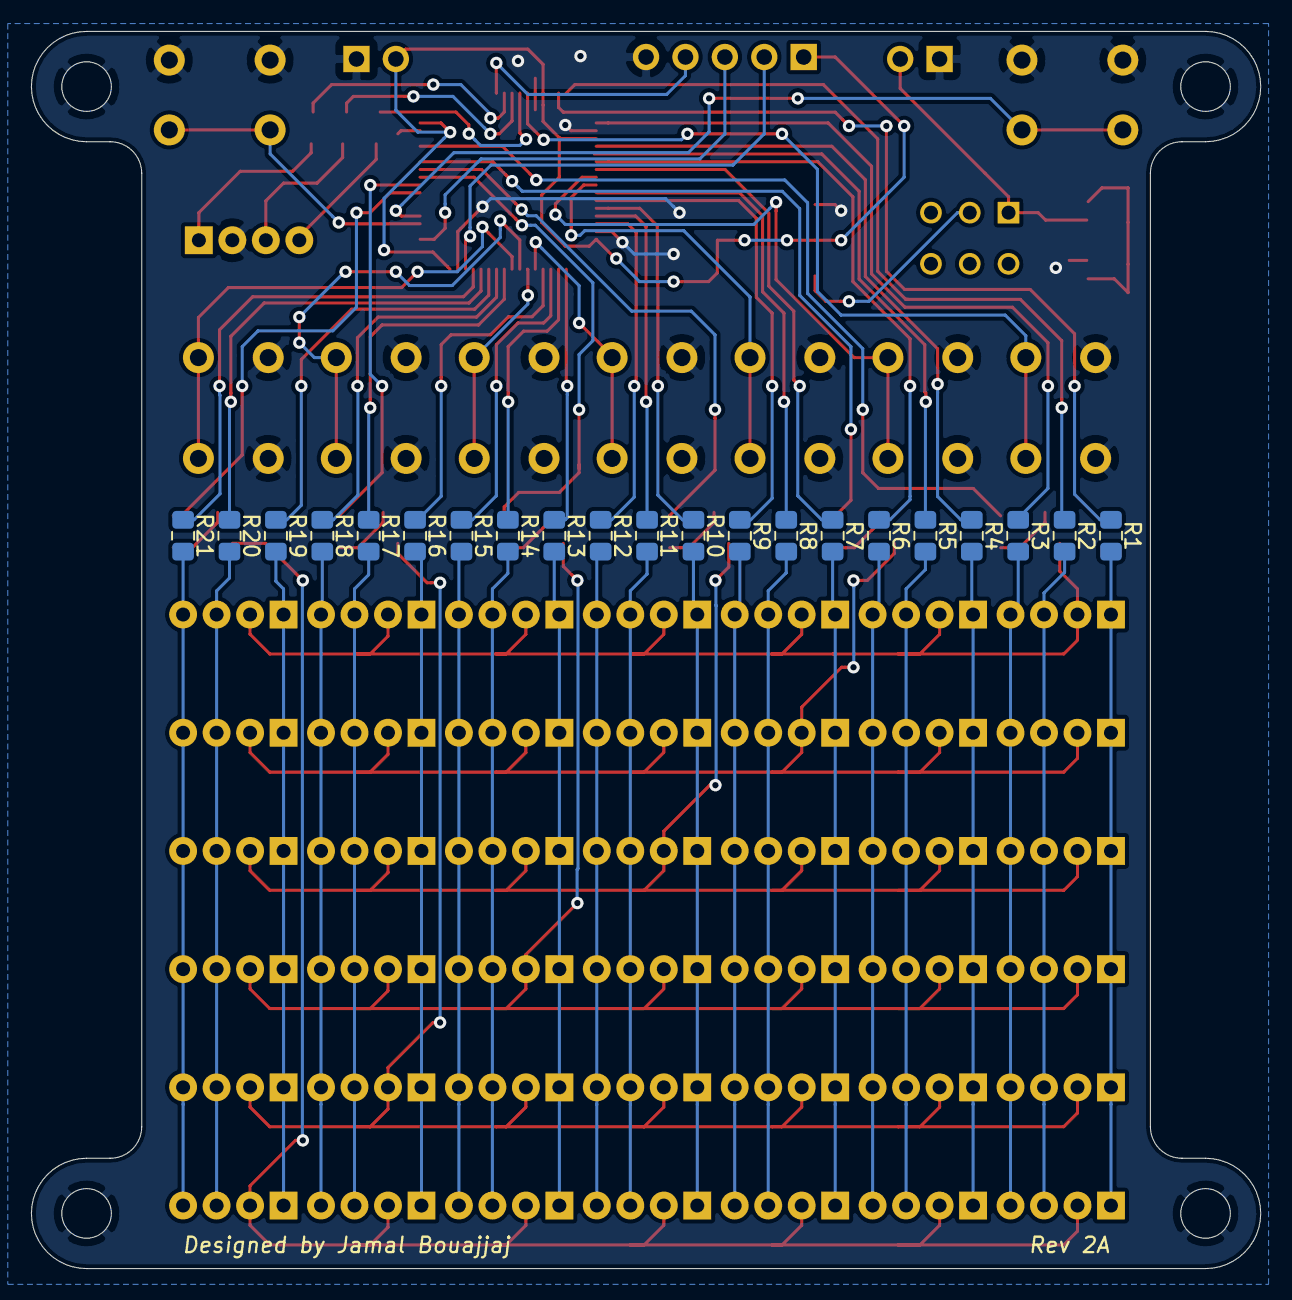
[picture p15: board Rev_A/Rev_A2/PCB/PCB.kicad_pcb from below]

Board: 2 copper layers, 79.2 x 79.8 mm, 100 parts (21 on the bottom side), 82 nets.

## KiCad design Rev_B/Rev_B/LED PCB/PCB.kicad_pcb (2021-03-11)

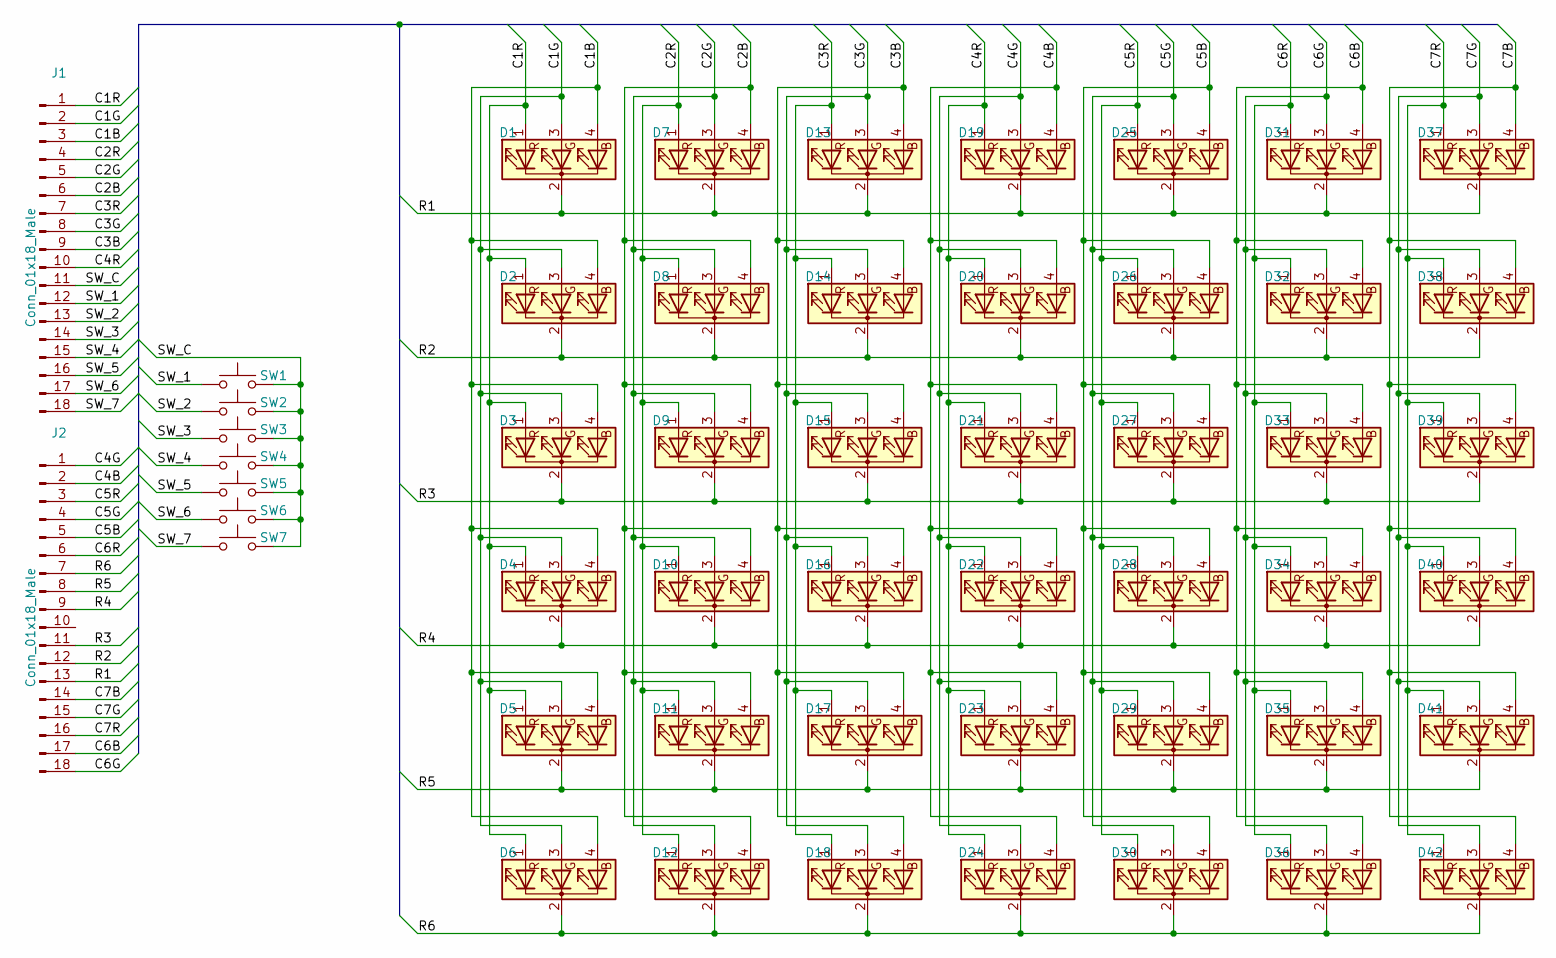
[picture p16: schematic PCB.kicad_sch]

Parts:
D1, D2, D3, D4, D5, D6, D7, D8, D9, D10, D11, D12, D13, D14, D15, D16, D17, D18, D19, D20, D21, D22, D23, D24, D25, D26, D27, D28, D29, D30, D31, D32, D33, D34, D35, D36, D37, D38, D39, D40, D41, D42: LED_RCGB; LED_D5.0mm-4_RGB_Staggered_Pins
J1, J2: Conn_01x18_Male; PinHeader_1x18_P2.54mm_Vertical
SW1, SW2, SW3, SW4, SW5, SW6, SW7: SW_Push; SW_PUSH_6mm_H8mm

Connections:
/C1B: D1.4 (BA), D2.4 (BA), D3.4 (BA), D4.4 (BA), D5.4 (BA), D6.4 (BA), J1.3
/C1G: D1.3 (GA), D2.3 (GA), D3.3 (GA), D4.3 (GA), D5.3 (GA), D6.3 (GA), J1.2
/C1R: D1.1 (RA), D2.1 (RA), D3.1 (RA), D4.1 (RA), D5.1 (RA), D6.1 (RA), J1.1
/C2B: D7.4 (BA), D8.4 (BA), D9.4 (BA), D10.4 (BA), D11.4 (BA), D12.4 (BA), J1.6
/C2G: D7.3 (GA), D8.3 (GA), D9.3 (GA), D10.3 (GA), D11.3 (GA), D12.3 (GA), J1.5
/C2R: D7.1 (RA), D8.1 (RA), D9.1 (RA), D10.1 (RA), D11.1 (RA), D12.1 (RA), J1.4
/C3B: D13.4 (BA), D14.4 (BA), D15.4 (BA), D16.4 (BA), D17.4 (BA), D18.4 (BA), J1.9
/C3G: D13.3 (GA), D14.3 (GA), D15.3 (GA), D16.3 (GA), D17.3 (GA), D18.3 (GA), J1.8
/C3R: D13.1 (RA), D14.1 (RA), D15.1 (RA), D16.1 (RA), D17.1 (RA), D18.1 (RA), J1.7
/C4B: D19.4 (BA), D20.4 (BA), D21.4 (BA), D22.4 (BA), D23.4 (BA), D24.4 (BA), J2.2
/C4G: D19.3 (GA), D20.3 (GA), D21.3 (GA), D22.3 (GA), D23.3 (GA), D24.3 (GA), J2.1
/C4R: D19.1 (RA), D20.1 (RA), D21.1 (RA), D22.1 (RA), D23.1 (RA), D24.1 (RA), J1.10
/C5B: D25.4 (BA), D26.4 (BA), D27.4 (BA), D28.4 (BA), D29.4 (BA), D30.4 (BA), J2.5
/C5G: D25.3 (GA), D26.3 (GA), D27.3 (GA), D28.3 (GA), D29.3 (GA), D30.3 (GA), J2.4
/C5R: D25.1 (RA), D26.1 (RA), D27.1 (RA), D28.1 (RA), D29.1 (RA), D30.1 (RA), J2.3
/C6B: D31.4 (BA), D32.4 (BA), D33.4 (BA), D34.4 (BA), D35.4 (BA), D36.4 (BA), J2.17
/C6G: D31.3 (GA), D32.3 (GA), D33.3 (GA), D34.3 (GA), D35.3 (GA), D36.3 (GA), J2.18
/C6R: D31.1 (RA), D32.1 (RA), D33.1 (RA), D34.1 (RA), D35.1 (RA), D36.1 (RA), J2.6
/C7B: D37.4 (BA), D38.4 (BA), D39.4 (BA), D40.4 (BA), D41.4 (BA), D42.4 (BA), J2.14
/C7G: D37.3 (GA), D38.3 (GA), D39.3 (GA), D40.3 (GA), D41.3 (GA), D42.3 (GA), J2.15
/C7R: D37.1 (RA), D38.1 (RA), D39.1 (RA), D40.1 (RA), D41.1 (RA), D42.1 (RA), J2.16
/R1: D1.2 (K), D7.2 (K), D13.2 (K), D19.2 (K), D25.2 (K), D31.2 (K), D37.2 (K), J2.13
/R2: D2.2 (K), D8.2 (K), D14.2 (K), D20.2 (K), D26.2 (K), D32.2 (K), D38.2 (K), J2.12
/R3: D3.2 (K), D9.2 (K), D15.2 (K), D21.2 (K), D27.2 (K), D33.2 (K), D39.2 (K), J2.11
/R4: D4.2 (K), D10.2 (K), D16.2 (K), D22.2 (K), D28.2 (K), D34.2 (K), D40.2 (K), J2.9
/R5: D5.2 (K), D11.2 (K), D17.2 (K), D23.2 (K), D29.2 (K), D35.2 (K), D41.2 (K), J2.8
/R6: D6.2 (K), D12.2 (K), D18.2 (K), D24.2 (K), D30.2 (K), D36.2 (K), D42.2 (K), J2.7
/SW_1: J1.12, SW1.1
/SW_2: J1.13, SW2.1
/SW_3: J1.14, SW3.1
/SW_4: J1.15, SW4.1
/SW_5: J1.16, SW5.1
/SW_6: J1.17, SW6.1
/SW_7: J1.18, SW7.1
/SW_C: J1.11, SW1.2, SW2.2, SW3.2, SW4.2, SW5.2, SW6.2, SW7.2

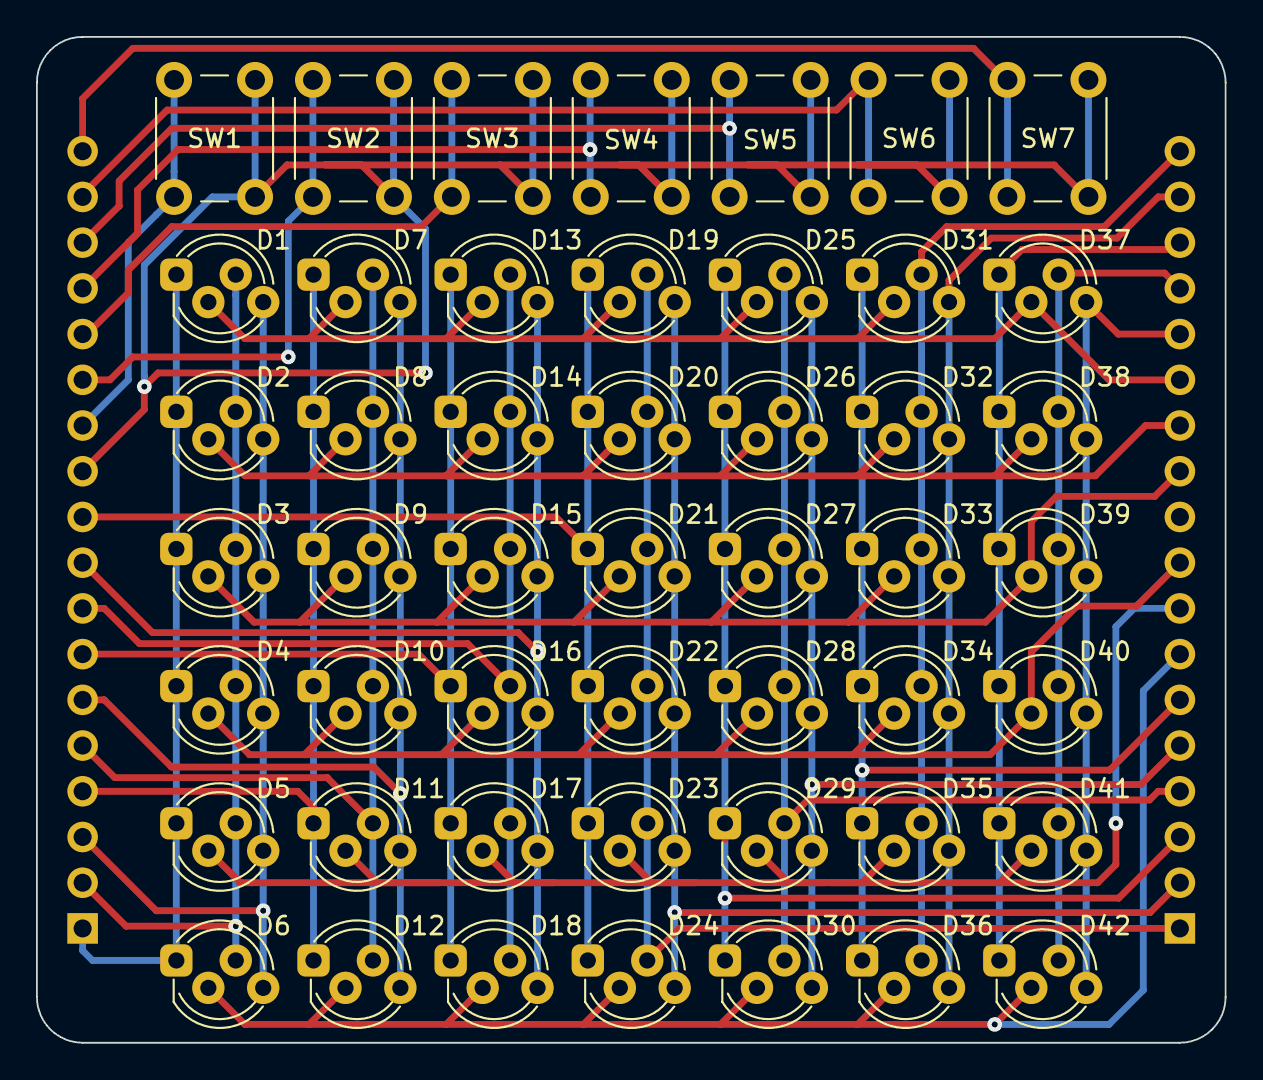
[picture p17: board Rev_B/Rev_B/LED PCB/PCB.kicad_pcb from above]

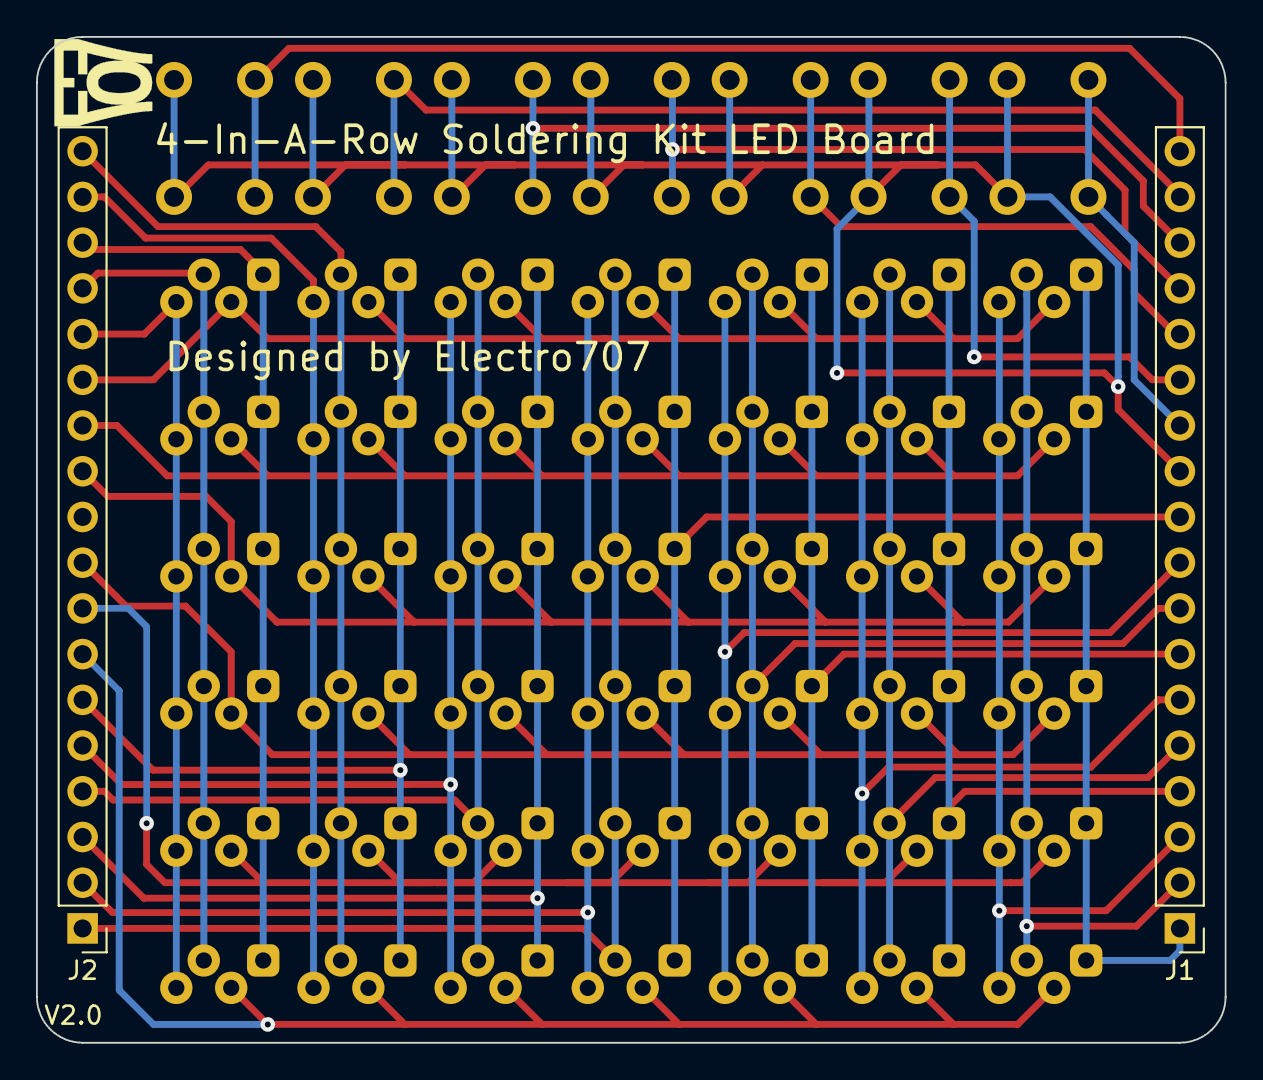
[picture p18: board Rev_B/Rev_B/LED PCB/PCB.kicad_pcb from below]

Board: 2 copper layers, 66.0 x 55.9 mm, 51 parts (2 on the bottom side), 35 nets.

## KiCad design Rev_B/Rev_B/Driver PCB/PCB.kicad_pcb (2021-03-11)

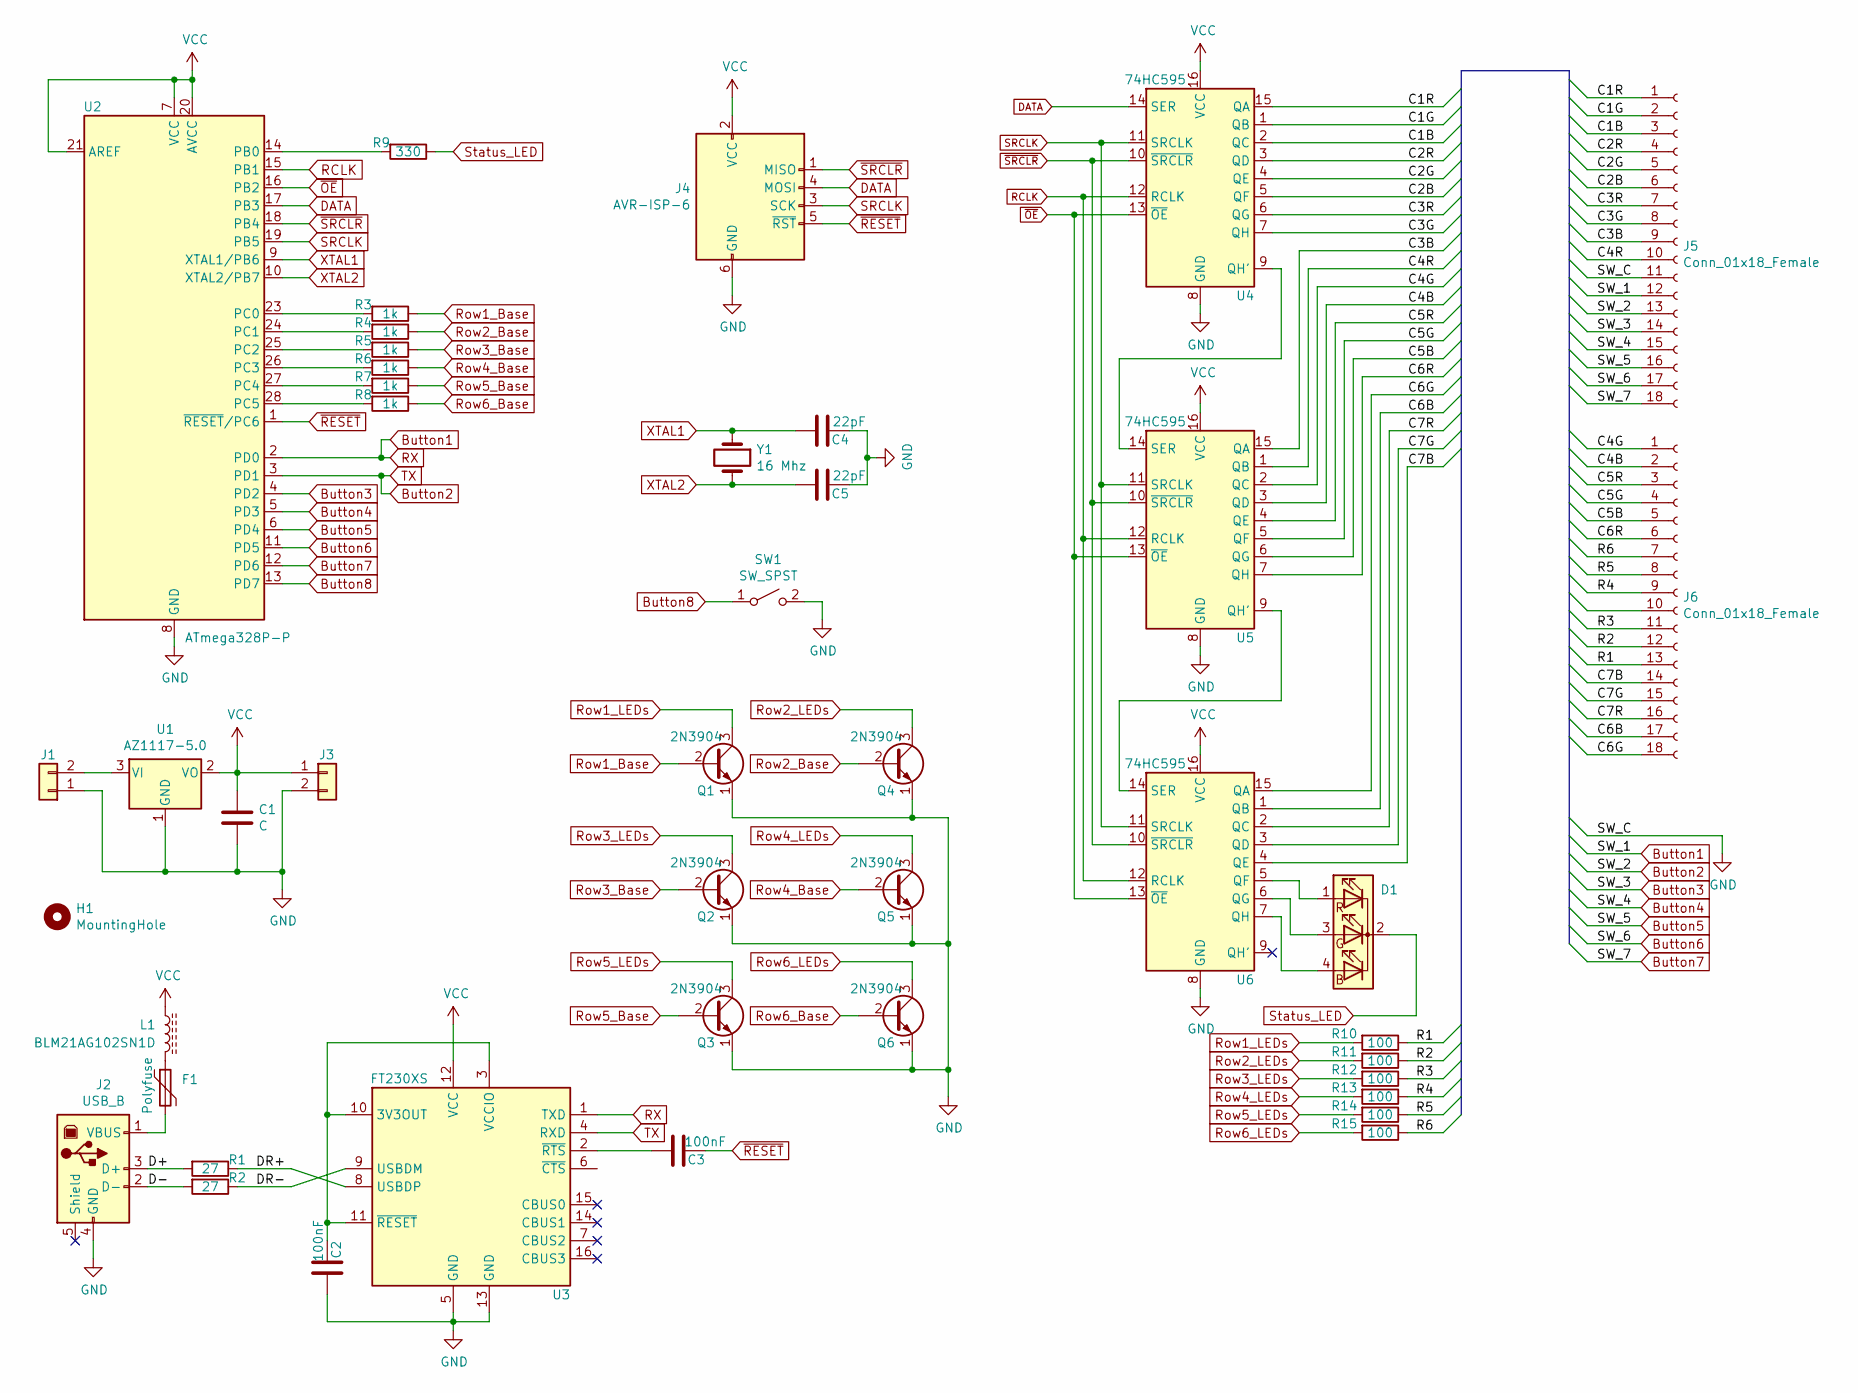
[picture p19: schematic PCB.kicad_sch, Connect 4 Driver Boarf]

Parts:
C1: C; C_0805_2012Metric_Pad1.18x1.45mm_HandSolder
C2, C3: 100nF; C_0805_2012Metric_Pad1.18x1.45mm_HandSolder
C4, C5: 22pF; C_Disc_D4.3mm_W1.9mm_P5.00mm
D1: LED_RCGB; LED_D5.0mm-4_RGB_Wide_Pins
F1: Polyfuse; Fuse_1206_3216Metric_Pad1.42x1.75mm_HandSolder
H1: MountingHole; MountingHole_3.2mm_M3_DIN965
J1, J3: Conn_01x02; PinSocket_1x02_P2.54mm_Vertical
J2: USB_B; USB_B_OST_USB-B1HSxx_Horizontal
J4: AVR-ISP-6; PinHeader_2x03_P2.54mm_Horizontal
J5, J6: Conn_01x18_Female; PinSocket_1x18_P2.54mm_Vertical
L1: BLM21AG102SN1D; L_0805_2012Metric_Pad1.15x1.40mm_HandSolder
Q1, Q2, Q3, Q4, Q5, Q6: 2N3904; TO-92_Wide
R1, R2: 27; R_0805_2012Metric_Pad1.20x1.40mm_HandSolder
R3, R4, R5, R6, R7, R8: 1k; R_Axial_DIN0207_L6.3mm_D2.5mm_P10.16mm_Horizontal
R9: 330; R_Axial_DIN0207_L6.3mm_D2.5mm_P10.16mm_Horizontal
R10, R11, R12, R13, R14, R15: 100; R_Axial_DIN0207_L6.3mm_D2.5mm_P10.16mm_Horizontal
SW1: SW_SPST; SW_PUSH_6mm_H5mm
U1: AZ1117-5.0; TO-220-3_Horizontal_TabDown
U2: ATmega328P-P; DIP-28_W7.62mm
U3: FT230XS; SSOP-16_3.9x4.9mm_P0.635mm
U4, U5, U6: 74HC595; DIP-16_W7.62mm_LongPads
Y1: 16 Mhz; Crystal_HC49-4H_Vertical

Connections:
/C1B: J5.3, U4.2 (QC)
/C1G: J5.2, U4.1 (QB)
/C1R: J5.1, U4.15 (QA)
/C2B: J5.6, U4.5 (QF)
/C2G: J5.5, U4.4 (QE)
/C2R: J5.4, U4.3 (QD)
/C3B: J5.9, U5.15 (QA)
/C3G: J5.8, U4.7 (QH)
/C3R: J5.7, U4.6 (QG)
/C4B: J6.2, U5.3 (QD)
/C4G: J6.1, U5.2 (QC)
/C4R: J5.10, U5.1 (QB)
/C5B: J6.5, U5.6 (QG)
/C5G: J6.4, U5.5 (QF)
/C5R: J6.3, U5.4 (QE)
/C6B: J6.17, U6.1 (QB)
/C6G: J6.18, U6.15 (QA)
/C6R: J6.6, U5.7 (QH)
/C7B: J6.14, U6.4 (QE)
/C7G: J6.15, U6.3 (QD)
/C7R: J6.16, U6.2 (QC)
/D+: J2.3 (D+), R1.2
/D-: J2.2 (D-), R2.2
/DR+: R1.1, U3.8 (USBDP)
/DR-: R2.1, U3.9 (USBDM)
/R1: J6.13, R10.1
/R2: J6.12, R11.1
/R3: J6.11, R12.1
/R4: J6.9, R13.1
/R5: J6.8, R14.1
/R6: J6.7, R15.1
Button1: J5.12, U2.2 (PD0), U3.1 (TXD)
Button2: J5.13, U2.3 (PD1), U3.4 (RXD)
Button3: J5.14, U2.4 (PD2)
Button4: J5.15, U2.5 (PD3)
Button5: J5.16, U2.6 (PD4)
Button6: J5.17, U2.11 (PD5)
Button7: J5.18, U2.12 (PD6)
Button8: SW1.1 (A), U2.13 (PD7)
DATA: J4.4 (MOSI), U2.17 (PB3), U4.14 (SER)
GND: C1.2, C2.2, C4.1, C5.1, J1.1, J2.4 (GND), J3.2, J4.6 (GND), J5.11, Q1.1 (E), Q2.1 (E), Q3.1 (E), Q4.1 (E), Q5.1 (E), Q6.1 (E), SW1.2 (B), U1.1 (GND), U2.8 (GND), U2.22 (GND), U3.5 (GND), U3.13 (GND), U4.8 (GND), U5.8 (GND), U6.8 (GND)
unnamed: C2.1, U3.3 (VCCIO), U3.10 (3V3OUT), U3.11 (~RESET)
unnamed: C3.2, U3.2 (~RTS)
unnamed: D1.1 (RA), U6.5 (QF)
unnamed: D1.3 (GA), U6.6 (QG)
unnamed: D1.4 (BA), U6.7 (QH)
unnamed: F1.1, L1.2
unnamed: F1.2, J2.1 (VBUS)
unnamed: J1.2, U1.3 (VI)
unnamed: R3.2, U2.23 (PC0)
unnamed: R4.2, U2.24 (PC1)
unnamed: R5.2, U2.25 (PC2)
unnamed: R6.2, U2.26 (PC3)
unnamed: R7.2, U2.27 (PC4)
unnamed: R8.2, U2.28 (PC5)
unnamed: R9.2, U2.14 (PB0)
unnamed: U4.9 (QH'), U5.14 (SER)
unnamed: U5.9 (QH'), U6.14 (SER)
RCLK: U2.15 (PB1), U4.12 (RCLK), U5.12 (RCLK), U6.12 (RCLK)
Row1_Base: Q1.2 (B), R3.1
Row1_LEDs: Q1.3 (C), R10.2
Row2_Base: Q4.2 (B), R4.1
Row2_LEDs: Q4.3 (C), R11.2
Row3_Base: Q2.2 (B), R5.1
Row3_LEDs: Q2.3 (C), R12.2
Row4_Base: Q5.2 (B), R6.1
Row4_LEDs: Q5.3 (C), R13.2
Row5_Base: Q3.2 (B), R7.1
Row5_LEDs: Q3.3 (C), R14.2
Row6_Base: Q6.2 (B), R8.1
Row6_LEDs: Q6.3 (C), R15.2
SRCLK: J4.3 (SCK), U2.19 (PB5), U4.11 (SRCLK), U5.11 (SRCLK), U6.11 (SRCLK)
Status_LED: D1.2 (K), R9.1
VCC: C1.1, J3.1, J4.2 (VCC), L1.1, U1.2 (VO), U2.7 (VCC), U2.20 (AVCC), U2.21 (AREF), U3.12 (VCC), U4.16 (VCC), U5.16 (VCC), U6.16 (VCC)
XTAL1: C4.2, U2.9 (XTAL1/PB6), Y1.1
XTAL2: C5.2, U2.10 (XTAL2/PB7), Y1.2
~OE: U2.16 (PB2), U4.13 (~OE), U5.13 (~OE), U6.13 (~OE)
~RESET: C3.1, J4.5 (~RST), U2.1 (~RESET~/PC6)
~SRCLR: J4.1 (MISO), U2.18 (PB4), U4.10 (~SRCLR), U5.10 (~SRCLR), U6.10 (~SRCLR)

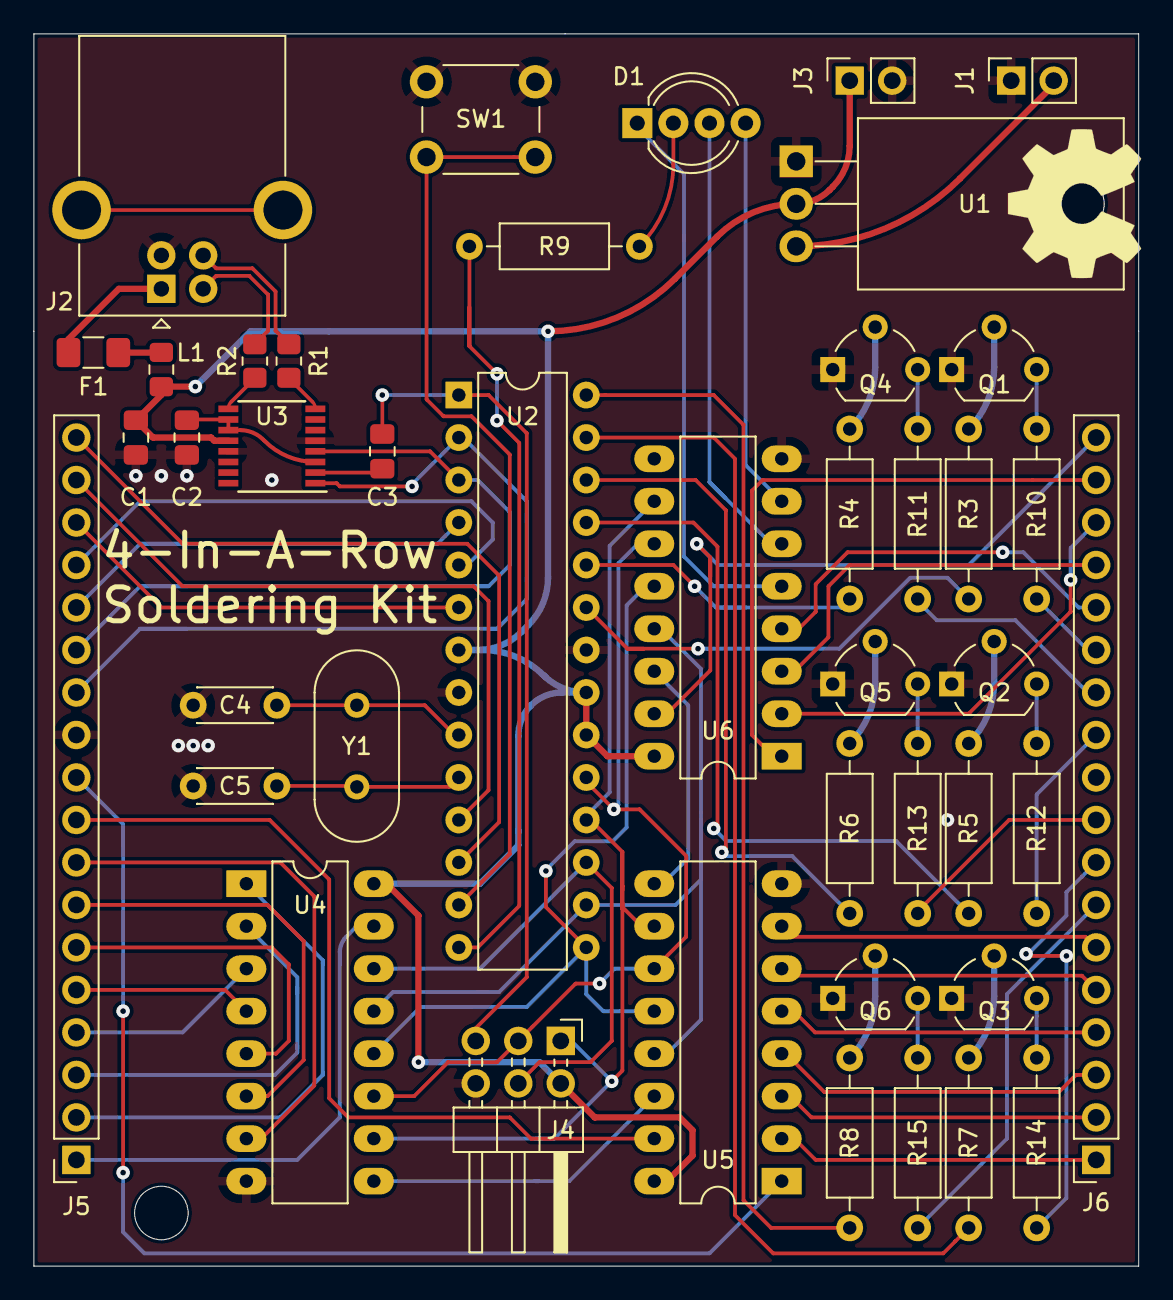
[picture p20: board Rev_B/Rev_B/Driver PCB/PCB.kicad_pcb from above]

Board: 2 copper layers, 66.0 x 73.7 mm, 44 parts (0 on the bottom side), 79 nets.

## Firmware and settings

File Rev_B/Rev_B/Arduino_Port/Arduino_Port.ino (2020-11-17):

/**
 * 4-in-a-row soldering kit Arduino code
 * Written by Jamal Bouajjaj / Electro707
 * 
 * This program is what primarily drives the 4-in-a-row soldering kit designed by me. 
 * 
 */
/****************************************************************************************************
    Defines and Macros
****************************************************************************************************/
/**Macro to enable the 74HC595's output*/
#define ENABLE_595_OUTPUT PORTB &= ~(1<<2) 
/**Macro to disable the 74HC595's output*/
#define DISABLE_595_OUTPUT PORTB |= (1<<2) 

/**Macro that switches the active player variable to 1 or 2 depending on it's current state*/
#define SWITCH_ACTIVE_PLAYER active_player = (active_player == 1) ? 2 : 1
/**Macro to get the LED color depending of which player is selected (1 or 2)*/
#define PLAYER_COLOR_SELECTOR(_PLAYER) (_PLAYER == 0b01) ? 0b001 : 0b011

/****************************************************************************************************
    Includes
****************************************************************************************************/
#include <SPI.h>
#include <avr/interrupt.h>
/****************************************************************************************************
    Global Variables
****************************************************************************************************/
/**
 * An array to store the each LED's color for each row.
 * 
 * This variable is directly pushed unto the shift registers
 */
uint32_t led[6];    
uint8_t current_row = 0; /**< Store the current row from 0-5 */
uint32_t current_led = 0; /**< Store the current output mask 0-2 (See ISR(TIMER0_OVF_vect) for more details)*/
uint8_t status_led_color = 0;   /**< Store the status's LED color */
/**
 * Store the player locations's in this array.
 * 
 * Each dimension of this array is a row, and in each element the columns are in groups of 2 bits.\n
 * For example, 0b001000 for row #0 means that player 2 is on the second column fo row 0. 
 */
uint16_t players[6];        
uint8_t active_player = 0; /**< Stores the active player. 1 for player 1, 2 for player 2 */
/**
 * Store the row and column of the "chips" that made a player won in order to blink them
 */
uint8_t winner_location[2][4];

/**
 * A mask variable to mask the leds and status_led_color with red, green, then blue (as only the red,
 * green, or blue LEDs can be on at a time due to the common-cathode).
 * \todo Option to "reduce brightness" by software reducing duty cycle (maybe add a dummy mask of 0's ?)
 */
uint32_t mask_test[] = {
  0b001001001001001001001001,
  0b010010010010010010010010,
  0b100100100100100100100100,
};

/****************************************************************************************************
    Function Prototypes
****************************************************************************************************/
void reset_shift_registers(void);
void playerToLed(void);
int waitForButtonInput(void);
void clearBuffer(uint16_t *c, int array_lenght);
uint8_t checkForWinner(void);
void end_of_game(uint8_t who_won);
void fill_display_led(uint8_t color);

void setup() {
  // put your setup code here, to run once:
  // Set the LED sink pins to a low output and high impedance
  PORTC = 0;
  DDRC = 0b111111;
  // Set the buttons to input pull-up
  DDRD = 0x00;
  PORTD = 0xFF;
  // Set up PORTB pins
  DDRB |= 0b00101111; // Set all pins to output except for crystal, MISO, and PB0
  reset_shift_registers();
  PORTB |= 1<<4; // Due to SRCLR pin being controlled by SPI, it now has a pull-up to avoid it going LOW
  DISABLE_595_OUTPUT;
  // Set up SPI module
  SPI.beginTransaction(SPISettings(8000000, MSBFIRST, SPI_MODE0));
  // Set up update timer
  TCCR2B = 2; // Set divider to CLK/8
  TIMSK2 = 0x01; // Set time interrupt
  
  // Clear LEDs variable
  for(int i=0;i<6;i++){led[i] = 0;}
  
  PORTB &= ~(1<<0);
  
  sei();
  ENABLE_595_OUTPUT;
  clearBuffer(players, 6);
   active_player = 1;      // Set the active player to player 1
  status_led_color = PLAYER_COLOR_SELECTOR(active_player);
}

void loop() {
  while(1){
    int c = waitForButtonInput();
    if(c == 7){
        end_of_game(0);
        continue;
    }
     _delay_ms(75);    // Delay for button noise
    int foundRow = 0;   // Variable to store if the lowest row has been found thru the for loop
    if(((players[0] >> (c*2)) & 0b11) == 0){    // Only switch player and find the row if the column isn't fully occupied
      for(int r=1;r<6;r++){   // Cycle thru all but one row
        players[r-1] |= active_player << (c*2);   // Set the row LED on of the last row on the loop
        if(r != 1){players[r-2] &= ~(0b11 << (c*2));}   // If the loop isn't the first one, set the last last row off
        playerToLed();    // Update the LED array to showcase the animation
        if(((players[r] >> (c*2)) & 0b11) != 0){    // If the row is occupied, exit the loop ( the led should be set from the last 2 lines)
          foundRow = 1;   // Set the foundRow variable to a 1
          break;    // Break out of the for loop
        }
        _delay_ms(75);    // Delay for animation
      }
      if(foundRow == 0){    // If didn't find the non-ocupied row, must be the last one
        players[5] |= active_player << (c*2);
        players[5-1] &= ~(0b11 << (c*2));
        playerToLed();
      }
      //number_of_turns++;      // Increase the number of turns
      uint8_t w = checkForWinner(); // Check for who, or none, player that one
            if(w != 0){
                end_of_game(w);
                continue;
            }
            SWITCH_ACTIVE_PLAYER;   // Switch the active player if the row isn't fully occupied
      status_led_color = PLAYER_COLOR_SELECTOR(active_player);
    }
  }
}


/**
 * This function ends the game by blinking the LED that made the player won,
 * then resets some variables
 * 
 * \param who_won The player who won the game if anybody won.\n
 * 0 For nobody\n
 * 1 For player 1\n
 * 2 For player 2
 */
void end_of_game(uint8_t who_won){
    // Blink thru the "chips" that won
    if (who_won!=0){
        //led_color = PLAYER_COLOR_SELECTOR(who_won);
        for(int i=0;i<5;i++){
            for(int k=0;k<4;k++){
                players[winner_location[0][k]] &= ~(0b11 << (winner_location[1][k]*2));
            }
            playerToLed();
            _delay_ms(400);
            for(int k=0;k<4;k++){
                players[winner_location[0][k]] |= (active_player << (winner_location[1][k]*2));
            }
            playerToLed();
            _delay_ms(400);
        }
    }
    else{
        uint8_t led_color = 0b111;
        fill_display_led(led_color);
        for(int i=0;i<5;i++){
            status_led_color = 0;
            _delay_ms(400);
            status_led_color = led_color;
            _delay_ms(400);
        }
    }
    fill_display_led(0);
    clearBuffer(players, 6);
    active_player = 1;
    status_led_color = PLAYER_COLOR_SELECTOR(active_player);
}

/**
 * A function that resets the shift register thru pin PB4
 * Because that pin is set to an input no matter what when the SPI periferal
 * is enabled, we must disable it before we're able to control the pin
 */
void reset_shift_registers(void){
  SPI.endTransaction();
  SPI.end();
  DDRB |= 1<<4; // Set reset pin as output
  PORTB |= 1<<4; // Set reset pin HIGH
  _delay_ms(20);
  PORTB &= ~(1<<4); // Set reset pin LOW
  _delay_ms(20);
  PORTB |= 1<<4; // Set reset pin HIGH
  _delay_ms(20);
  DDRB &= ~(1<<4); // Set reset pin as input
}

/**
 * The LED updater interupt, beign triggered by Timer0
 * 
 * The LEDs are updated by using the shift registers, only turning on the red, green, then blue LEDs
 * during each row update.
 */
ISR(TIMER2_OVF_vect){
  PORTB &= ~(1<<1);
  //uint32_t to_s = (uint32_t)led[current_row] & (1L<<current_led);
  uint32_t to_s = ((uint32_t)led[current_row] | ((uint32_t)status_led_color << 21)) & mask_test[current_led];
  SPI.transfer(to_s >> 16);
  SPI.transfer(to_s >> 8);
  SPI.transfer(to_s >> 0);
  PORTB |= (1<<1);
  //if (++current_led == 12){
  if (++current_led == 3){
    current_led = 0;
    if (++current_row == 6){
      current_row = 0;
    }
    PORTC = 1<<current_row;
  }
}

/**
 * A function that converts the players array into the led array in order to be
 * outputed.
 * Because I wanted to prevent any flicker effect while the array is beign updated,
 * the interupts (the only one that exists is the LED updater one) are disabled while
 * the led array is beign eidted.
 */
void playerToLed(void){
  cli();
  for(int r=0;r<6;r++){
    led[r] = 0L; // Clear LED buffer
    for(int c=0;c<7;c++){
      uint8_t playerAtLoc = (players[r] >> (c*2)) & 0b11;
      uint8_t to_shift = 0;
      if(playerAtLoc != 0){
                to_shift = PLAYER_COLOR_SELECTOR(playerAtLoc);
            }
      led[r] |= ((uint32_t)to_shift << (c*3));
    }
  }
  sei();
}

/**
 * A function that waits until one of the buttons are pressed 
 * (either the column buttons or the generic button).
 * 
 * \return A number 0-6 corresponding to the column button pressed
 * or 7 for the general button
 */
int waitForButtonInput(void){
  while(PIND == 0xFF);
  for(int i=0;i<8;i++){ // Look for the button number that is pressed
    if(((PIND >> i) & 0b1) == 0){
      return i;
    }
  }
  return 0;
}

/**
 * A function that clears a 16-bit buffer with a given array_lenght
 * \todo Turn this into a macro
 */
void clearBuffer(uint16_t *c, int array_lenght){
  for(int i=0;i<array_lenght;i++){
    c[i] = 0;
  }
}

/**
 * A function that fills the entire display with a certain color
 * \param color The color to turn the display into. Need to be only 3-bits in size
 */
void fill_display_led(uint8_t color){
    cli();
  for(int r=0;r<6;r++){
        led[r] = 0L;
    for(int c=0;c<7;c++){
      led[r] |= ((uint32_t)color << (c*3));
    }
  }
  sei();
}

/**
 * A function to check for a game winner
 * \return 0 if no player won, 1 for player 1, and 2 for player 2
 * \note Thanks Spencer Hopwood for this function :)
 */
uint8_t checkForWinner(){
    int c, r, i;
  // Check vertical
  for(c=0;c<7;c++){   // Check every column
    uint8_t similarCounter = 0;   // Stores the number of same player in a row
    uint8_t simlarPlayer = 0;   // Stores the player for the previous variable
    for(r=0;r<(6-1);r++){
      if( ((players[r]>>(c*2)) & 0b11) == ((players[r+1]>>(c*2)) & 0b11) ){   // If the player from the current and next row is the same, increment a counter
        if(((players[r]>>(c*2)) & 0b11) != 0){      // Only increment counter if the player isn't 0 (none)
          simlarPlayer = (players[r]>>(c*2))&0b11;  // Record the similar player
          winner_location[0][similarCounter] = r;
                    winner_location[1][similarCounter] = c;
          similarCounter++;             // Increment counter
          if(similarCounter >= 3){          // If counter is increment to 3 ( repreating player 4 times), return
            break;
          }
        }
      }
      else{     // If the player isn't the same as the next row, reset the counter and player variable
        similarCounter = 0;
        simlarPlayer = 0;
      }
    }
    // If there was a similarity, exit and return the player number
    if(similarCounter >= 3){
            winner_location[0][similarCounter] = r+1;
            winner_location[1][similarCounter] = c;
      return simlarPlayer;
    }
  }

  // Check horizontal
  for(r=0;r<6;r++){   // Check every row
    uint8_t similarCounter = 0;   // Stores the number of same player in a column
    uint8_t simlarPlayer = 0;   // Stores the player for the previous variable
    for(c=0;c<(7-1);c++){
      if( ((players[r]>>(c*2)) & 0b11) == ((players[r]>>((c+1)*2)) & 0b11) ){   // If the player from the current and next column is the same, increment a counter
        if(((players[r]>>(c*2)) & 0b11) != 0){      // Only increment counter if the player isn't 0 (none)
          simlarPlayer = (players[r]>>(c*2))&0b11;  // Record the similar player
          winner_location[0][similarCounter] = r;
                    winner_location[1][similarCounter] = c;
          similarCounter++;             // Increment counter
          if(similarCounter >= 3){          // If counter is increment to 3 ( repreating player 4 times), return
            break;
          }
        }
      }
      else{     // If the player isn't the same as the next row, reset the counter and player variable
        similarCounter = 0;
        simlarPlayer = 0;
      }
    }
    // If there was a similarity, exit and return the player number
    if(similarCounter >= 3){
            winner_location[0][similarCounter] = r;
            winner_location[1][similarCounter] = c+1;
      return simlarPlayer;
    }
  }

  // Check diagonal (positive slope)
  // Check 4 diagonal in a row from the last 3 row and the first 4 column ( the only combination)
  for(c=0;c<4;c++){
    for(r=3;r<6;r++){
      uint8_t similarCounter = 0;   // Stores the number of same player in a column
      uint8_t simlarPlayer = 0;   // Stores the player for the previous variable
      for(i=0;i<(4-1);i++){
        if( ((players[r-i]>>((c+i)*2)) & 0b11) == ((players[r-i-1]>>((c+i+1)*2)) & 0b11) ){   // If the player from the current and next column is the same, increment a counter
          if(((players[r-i]>>((c+i)*2)) & 0b11) != 0){      // Only increment counter if the player isn't 0 (none)
            simlarPlayer = (players[r-i]>>((c+i)*2)) & 0b11;  // Record the similar player
            winner_location[0][similarCounter] = r-i;
                        winner_location[1][similarCounter] = c+i;
            similarCounter++;             // Increment counter
            if(similarCounter >= 3){          // If counter is increment to 3 ( repreating player 4 times), return
              break;
            }
          }
        }
        else{     // If the player isn't the same as the next row, reset the counter and player variable
          similarCounter = 0;
          simlarPlayer = 0;
        }
      }
      // If there was a similarity, exit and return the player number
      if(similarCounter >= 3){
                winner_location[0][similarCounter] = r-i-1;
                winner_location[1][similarCounter] = c+i+1;
        return simlarPlayer;
      }
    }
  }

  // Check diagonal (negative slope)
  // Check 4 diagonal in a row from the last 3 row and the first 4 column ( the only combination)
  for(c=6;c>2;c--){
    for(r=3;r<6;r++){
      uint8_t similarCounter = 0;   // Stores the number of same player in a column
      uint8_t simlarPlayer = 0;   // Stores the player for the previous variable
      for(i=0;i<(4-1);i++){
        if( ((players[r-i]>>((c-i)*2)) & 0b11) == ((players[r-i-1]>>((c-i-1)*2)) & 0b11) ){   // If the player from the current and next column is the same, increment a counter
          if(((players[r-i]>>((c-i)*2)) & 0b11) != 0){      // Only increment counter if the player isn't 0 (none)
            simlarPlayer = (players[r-i]>>((c-i)*2)) & 0b11;  // Record the similar player
            winner_location[0][similarCounter] = r-i;
                        winner_location[1][similarCounter] = c-i;
            similarCounter++;             // Increment counter
            if(similarCounter >= 3){          // If counter is increment to 3 ( repreating player 4 times), return
              break;
            }
          }
        }
        else{     // If the player isn't the same as the next row, reset the counter and player variable
          similarCounter = 0;
          simlarPlayer = 0;
        }
      }
      // If there was a similarity, exit and return the player number
      if(similarCounter >= 3){
                winner_location[0][similarCounter] = r-i-1;
                winner_location[1][similarCounter] = c-i-1;
        return simlarPlayer;
      }
    }
  }
  return 0;
}

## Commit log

2019-11-10 Added Schematic.pdf
2019-11-10 Removed TheGame_1 as a submodule.
    [TheGame_1 Run.cfg]
2020-11-17 sync with local copy. Many updates
    [Buttom Part.0009.ipt, Buttom Part.ipt, Buttom.stl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]
2021-03-11 Major versioning revision. Added V7 with it semi-finalized
    [Buttom Part.0009.ipt, Buttom Part.ipt, Buttom.stl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]
2021-03-13 Removed a lot of bloat. Made RevB's lookable/loadable by a patch file (for B1, B2, ...)
    [Buttom Part.0009.ipt, Buttom Part.ipt, Buttom.stl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]
